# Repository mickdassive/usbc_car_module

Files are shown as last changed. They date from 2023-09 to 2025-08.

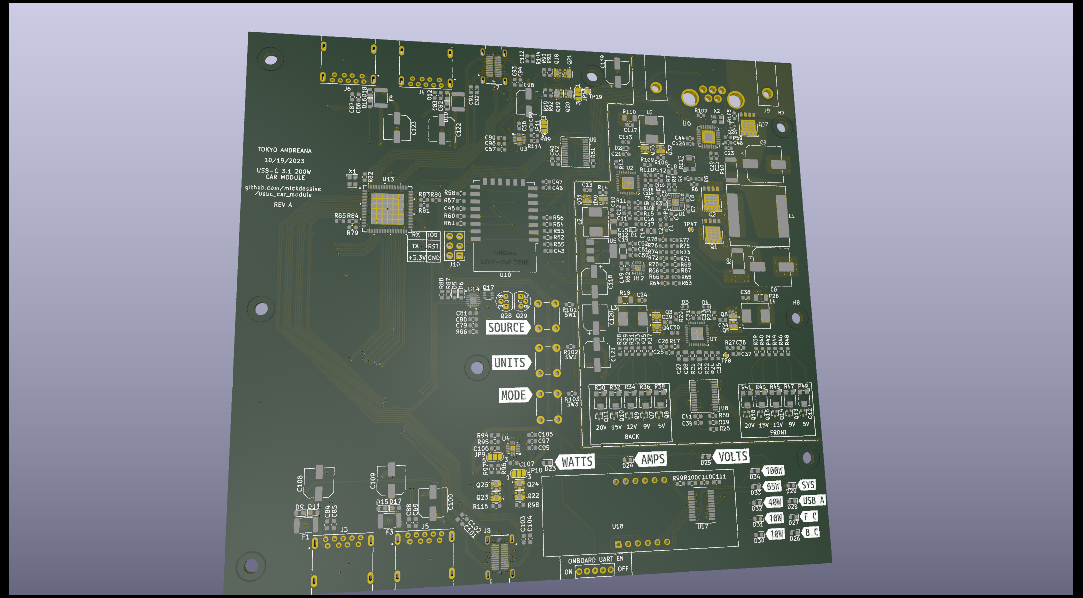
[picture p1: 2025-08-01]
hardware/renders/nopart.png

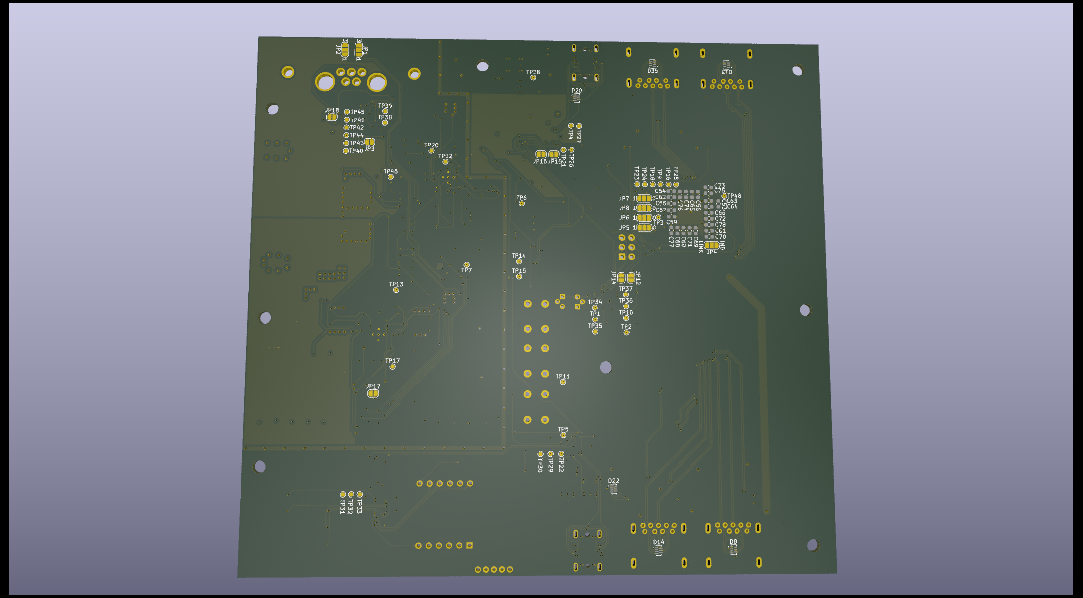
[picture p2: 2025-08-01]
hardware/renders/nopartback.png

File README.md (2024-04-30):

# USB 3.1x1 Hub with USB-C and USB-A Ports

This project is a USB 3.1x1 hub designed with KiCad 8.0 and developed with PlatformIO. It features two USB-C ports (one downstream and one upstream) capable of delivering up to 100W power, along with four regular downstream USB-A ports.

## Features

- USB 3.1x1 hub with USB-C and USB-A ports
- Supports up to 100W power delivery per port
- Onboard UART transceiver for programming the main MCU (ESP-12F)
- Onboard CAN bus transceiver for automotive applications
- Utilizes USB5926C hub chip from Microchip
- USB PD PHYs (PTN110N) from NXP
- Includes a display and ADC for power monitoring:
  - Monitor individual power consumption of USB-C ports (upstream and downstream)
  - Monitor combined total power consumption of USB-A ports
  - Monitor total system power consumption

## Contributors

- [Tokyo Andreana](https://github.com/mickdassive)

## License

This project is licensed under the [GNU General Public License v3.0](LICENSE).

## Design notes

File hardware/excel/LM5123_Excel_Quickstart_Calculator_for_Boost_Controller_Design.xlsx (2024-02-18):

 | LM5123 BOOST Controller Design Tool
ABOUT |  | =Input Box |  |  |  | TERMS OF USE
 |  |  |  |  |  | Rev 0.2 | December-2021
Step 1: Design Specifications
 |  |  | Minimum Input Supply Voltage , VSUPPLY(min) | 10 | V
 |  |  | Typical Input Supply Voltage, VSUPPLY(typ) | 12 | V
 |  |  | Maximum Input Supply Voltage , VSUPPLY(max) | 18 | V
 |  |  | Output Target Voltage, VLOAD | 21 | V
 |  |  | Maximum Output Current , ILOAD | 15.00 | A
 |  |  | Light load operation switching mode | DEM
 |  |  | Free Running Switching Frequency, FSW | 2000 | kHz
 |  |  | Free running Oscillator Set Resistor, RT | 10.10 | kΩ
 |  |  | Output Power, POUT | 315.0 | W
 |  |  | Boost Converter Duty Cycle Limit of LM5123 at VSUPPLY(MIN) | 79.8 | %
 |  |  | Ideal Duty Cycle at VSUPPLY(MIN) | 52.4 | %
Step 2: Filter Inductor
 |  |  | Switching mode at VSUPPLY(min) | CCM
 |  |  | Desired Maximum Inductor Current Ripple Ratio | 10 | %
 |  |  | Recommended Inductance (LM_CALC) | 1.037 | uH
 |  |  | User Selection. Inductance, (LM) | 1 | uH
 |  |  | Max Inductor DCR, RDCR | 1.38 | mΩ
 |  |  | Peak inductor current, ILPK | 32.81 | A
Step 3: Current Sense Resistor Selection
 |  |  | Peak Current Limit Margin | 10 | %
 |  |  | Selected Peak Current limit(ILPK_select) | 37.91 | A
 |  |  | Recommended current sense Resistor (RS) | 1.58 | mΩ
 |  |  | Selected current sense Resistor (RS) | 1.5 | mΩ
 |  |  | Actual inductor peak current limit | 40.00 | A
Step 4: Output Capacitor Selection
 |  |  | Desired load step ripple voltage (ΔvOUT) | 240 | mV
 |  |  | Minimum output capacitance | 492.19 | uF
 |  |  | Selected Output Capacitance (COUT) | 470 | uF
 |  |  | Equivalent COUT ESR (RESR) | 8 | mΩ
Step 6: Soft-Start Capacitor Selection
 |  |  | Suggested minimum soft-start capacitor (CSS_MIN) | 13.16 | nF
 |  |  | Desied soft-start time at minimum input voltage (TSS) | 10 | ms
 |  |  | Calculated soft-start capacitor (CSS) | 381.8181818 | nF
Step 5: UVLO Resistor Divider Selection
 |  |  | Desired voltage On (VUVLO_ON) | 11.2 | V
 |  |  | Desired voltage OFF (VUVLO_OFF) | 10 | V
 |  |  | Calculated top UVLO resistor value (RUVT_CALC) | 94.55 | kΩ
 |  |  | Selected top UVLO resistor value (RUVT) | 100 | kΩ
 |  |  | Bottom UVLO Resistor (RUVB) | 10.891 | kΩ
Step 7: Loop Compensation
 |  |  | Voltage selected (VIN_VAR) | 12V
 |  |  | VREF Resistor Selection
 |  |  | Suggested output voltage range | High
 |  |  | Track pin voltage to set the output voltage (VTRK) | 0.350 | V
 |  |  | Minimum value for (RVREFT_min) | 13.0 | kΩ
 |  |  | Maximum value for (RVREFT_max) | 22.8 | kΩ
 |  |  | Select a top VREF resistor between RVREFT_min and RVREFT_max (RVREFT) | 20 | kΩ
 |  |  | Calculated bottom feedback resistor (RVREFB_calc) | 10.8 | kΩ
 |  |  | Select a bottomresistor based on calculated balue(RVREFB) | 11 | kΩ
 |  |  | Suggested bandwidth (FCO_calc) | 10.1 | kHz
 |  |  | Selected bandwidth (FCO) | 5.5 | kHz
 |  | Calculated |  | Selected
 | RCOMP | 30.3 | kΩ | 35 | kΩ
 | CCOMP | 2.9 | nF | 3.3 | nF
 | CHF | 23.58068651 | pF | 100 | pF
Efficiency / Power Loss Analyzer
Low-Side MOSFET Parameters (QLS)
 |  |  | On-State Resistance, RDS(on) | 8.8 | mΩ
 |  |  | Total Gate Charge, QG | 10 | nC
 |  |  | Gate-Drain Charge, QGD | 2.4 | nC
 |  |  | Gate-Source Charge, QGS | 4.5 | nC
 |  |  | Gate Resistance, RG | 0 | Ω
 |  |  | Gate-Source Threshold Voltage, VTH | 1.7 | V
High-Side MOSFET Parameters (QHS)
 |  |  | On-State Resistance, (RDS(on)) | 8.8 | mΩ
 |  |  | Total Gate Charge, (QG) | 10 | nC
 |  |  | Gate-Drain Charge, (QGD) | 2.4 | nC
 |  |  | Gate-Source Charge, (QGS) | 4.5 | nC
 |  |  | Gate Resistance, (RG) | 0 | Ω
 |  |  | Gate-Source Threshold Voltage, (VTH) | 1.7 | V
 |  |  | Body Diode Reverse Recovery Charge (QRR) | 33 | nC
 |  |  | Body Diode Forward Voltage Drop (VD_BD) | 0.8 | V

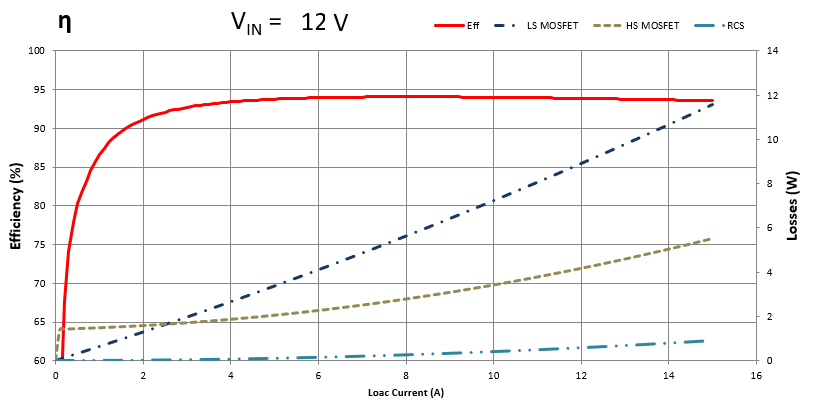
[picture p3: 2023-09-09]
hardware/Capture.PNG

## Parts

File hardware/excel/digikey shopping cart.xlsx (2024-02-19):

Index | Quantity | Part Number | Manufacturer Part Number | Description | Customer Reference | Available | Backorder | Unit Price | Extended Price CAD
1 | 10 | P15436CT-ND | EEH-ZA1E101XP | CAP ALUM HYB 100UF 20% 25V SMD |  | 10 | 0 | 1.356 | 13.56
2 | 1000 | 1276-1935-1-ND | CL10B104KB8NNWC | CAP CER 0.1UF 50V X7R 0603 |  | 1000 | 0 | 0.00665 | 6.65
3 | 100 | 1276-1102-1-ND | CL10A105KA8NNNC | CAP CER 1UF 25V X5R 0603 |  | 100 | 0 | 0.0188 | 1.88
4 | 50 | 445-9050-1-ND | C1608X5R1E475K080AC | CAP CER 4.7UF 25V X5R 0603 |  | 50 | 0 | 0.123 | 6.15
5 | 50 | 490-10731-1-ND | GRM188R61E225KA12D | CAP CER 2.2UF 25V X5R 0603 | 50 | 50 | 0 | 0.08 | 4.00
6 | 50 | 490-GRM188R61E106KA73JCT-ND | GRM188R61E106KA73J | CAP CER 10UF 25V X5R 0603 |  | 50 | 0 | 0.169 | 8.45
7 | 50 | 1292-1494-1-ND | 0603N180J500CT | CAP CER 18PF 50V C0G/NP0 0603 |  | 50 | 0 | 0.019 | 0.95
8 | 25 | 1276-CL10B474KA8VPJCCT-ND | CL10B474KA8VPJC | CAP CER 470NF 25V X7R 0603 |  | 25 | 0 | 0.313 | 7.83
9 | 50 | 399-C0603C471J5GAC7867CT-ND | C0603C471J5GAC7867 | CAP CER 470PF 50V C0G/NP0 0603 |  | 50 | 0 | 0.0414 | 2.07
10 | 10 | 445-14141-1-ND | C1608X5R1E335K080AC | CAP CER 3.3UF 25V X5R 0603 |  | 10 | 0 | 0.279 | 2.79
11 | 10 | P18963CT-ND | EEE-FK1V471SP | CAP ALUM 470UF 20% 35V SMD |  | 10 | 0 | 1.097 | 10.97
12 | 10 | 10-EEE-FN1J121UPCT-ND | EEE-FN1J121UP | CAP ALUM 120UF 20% 63V SMD |  | 10 | 0 | 0.988 | 9.88
13 | 50 | 1292-1424-1-ND | 0603B273K250CT | CAP CER 0.027UF 25V X7R 0603 |  | 50 | 0 | 0.0388 | 1.94
14 | 50 | 399-C0603C151J5GAC7867CT-ND | C0603C151J5GAC7867 | CAP CER 150PF 50V C0G/NP0 0603 |  | 50 | 0 | 0.026 | 1.30
15 | 1000 | 541-10.0KHCT-ND | CRCW060310K0FKEA | RES SMD 10K OHM 1% 1/10W 0603 |  | 1000 | 0 | 0.01246 | 12.46
16 | 1000 | RMCF0603FT100KCT-ND | RMCF0603FT100K | RES 100K OHM 1% 1/10W 0603 |  | 1000 | 0 | 0.00645 | 6.45
17 | 50 | TC33X-103ECT-ND | TC33X-2-103E | TRIMMER 10K OHM 0.1W J LEAD TOP |  | 50 | 0 | 0.3564 | 17.82
18 | 100 | 541-1.00KHCT-ND | CRCW06031K00FKEA | RES SMD 1K OHM 1% 1/10W 0603 |  | 100 | 0 | 0.0213 | 2.13
19 | 100 | 541-0.0GCT-ND | CRCW06030000Z0EA | RES SMD 0 OHM JUMPER 1/10W 0603 |  | 100 | 0 | 0.0175 | 1.75
20 | 10 | WSLP-.01CT-ND | WSLP1206R0100FEA | RES 0.01 OHM 1% 1W 1206 |  | 10 | 0 | 0.685 | 6.85
21 | 50 | 541-4055-1-ND | CRCW0603470RJNEBC | RES SMD 470 OHM 5% 1/10W 0603 |  | 50 | 0 | 0.0204 | 1.02
22 | 50 | 13-RT0603BRE075KLCT-ND | RT0603BRE075KL | RES 5K OHM 0.1% 1/10W 0603 |  | 50 | 0 | 0.1428 | 7.14
23 | 50 | 541-5184-1-ND | CRCW060315R0FKEAC | RES 15 OHM 1% 1/10W 0603 |  | 50 | 0 | 0.0236 | 1.18
24 | 50 | 541-4060-1-ND | CRCW0603330RJNEAC | RES SMD 330 OHM 5% 1/10W 0603 |  | 50 | 0 | 0.0204 | 1.02
25 | 10 | 541-10147-1-ND | WSLP25121L500FEA | RES 0.0015 OHM 1% 3W 2512 |  | 10 | 0 | 1.127 | 11.27
26 | 50 | 541-5.90KHCT-ND | CRCW06035K90FKEA | RES SMD 5.9K OHM 1% 1/10W 0603 |  | 50 | 0 | 0.0252 | 1.26
27 | 50 | 541-5344-1-ND | CRCW060330K0FKEAC | RES 30K OHM 1% 1/10W 0603 |  | 50 | 0 | 0.0236 | 1.18
28 | 50 | 13-RC0603FR-1322KLCT-ND | RC0603FR-1322KL | RES 22K OHM 1% 1/10W 0603 |  | 50 | 0 | 0.017 | 0.85
29 | 50 | 13-RC0402FR-0735KLCT-ND | RC0402FR-0735KL | RES 35K OHM 1% 1/16W 0402 |  | 50 | 0 | 0.0134 | 0.67
30 | 50 | 13-RC0603FR-1020KLCT-ND | RC0603FR-1020KL | RES 20K OHM 1% 1/10W 0603 |  | 50 | 0 | 0.017 | 0.85
31 | 25 | 541-120HCT-ND | CRCW0603120RFKEA | RES SMD 120 OHM 1% 1/10W 0603 |  | 25 | 0 | 0.039 | 0.98
32 | 50 | 541-4057-1-ND | CRCW060310R0JNEAC | RES SMD 10 OHM 5% 1/10W 0603 |  | 50 | 0 | 0.0204 | 1.02
33 | 10 | 541-4046-1-ND | CRCW060312K0FKEAC | RES SMD 12K OHM 1% 1/10W 0603 |  | 10 | 0 | 0.038 | 0.38
34 | 5 | TC33X-102ECT-ND | TC33X-2-102E | TRIMMER 1K OHM 0.1W J LEAD TOP |  | 5 | 0 | 0.43 | 2.15
35 | 4 | 541-1008-1-ND | IHLP2525CZER2R2M01 | FIXED IND 2.2UH 8A 20 MOHM SMD |  | 4 | 0 | 1.72 | 6.88
36 | 2 | 541-1250-1-ND | IHLP6767GZER1R0M01 | FIXED IND 1UH 48A 1.38 MOHM SMD |  | 2 | 0 | 5.86 | 11.72
37 | 2 | 541-1004-1-ND | IHLP2525CZERR68M01 | FIXED IND 680NH 15.5A 5.5MOHM SM |  | 2 | 0 | 1.84 | 3.68
38 | 2 | 541-IHLP2525CZER1R0M11CT-ND | IHLP2525CZER1R0M11 | FIXED IND 1UH 12.5A 8 MOHM SMD |  | 2 | 0 | 1.84 | 3.68
39 | 10 | RB520S30T1GOSCT-ND | RB520S30T1G | DIODE SCHOTTKY 30V 200MA SOD523 |  | 10 | 0 | 0.157 | 1.57
40 | 25 | 1801-TS4148RCGCT-ND | TS4148 RCG | DIODE GEN PURP 75V 100MA 0603 |  | 25 | 0 | 0.195 | 4.88
41 | 10 | UCLAMP0501HCT-ND | UCLAMP0501H.TCT | TVS DIODE 5VWM 12.5VC SOD523 |  | 10 | 0 | 0.701 | 7.01
42 | 100 | 67-1548-1-ND | SML-LX0603IW-TR | LED RED DIFFUSED SMD |  | 100 | 0 | 0.1758 | 17.58
43 | 4 | 296-LM5143QRWGRQ1CT-ND | LM5143QRWGRQ1 | IC POWER MANAGEMENT |  | 4 | 0 | 19.33 | 77.32
44 | 10 | NCP177AMX120TCGOSCT-ND | NCP177AMX120TCG | IC REG LINEAR 1.2V 500MA 4XDFN |  | 10 | 0 | 0.533 | 5.33
45 | 4 | PI4IOE5V6416LEXDICT-ND | PI4IOE5V6416LEX | IC XPNDR 400KHZ I2C 24TSSOP |  | 4 | 0 | 2.26 | 9.04
46 | 4 | 568-13082-1-ND | PTN5100BSMP | IC USB PD PHY TYPE C 20HVQFN |  | 4 | 0 | 4.22 | 16.88
47 | 2 | 296-LM51231QRGRRQ1CT-ND | LM51231QRGRRQ1 | 2.2-MHZ WIDE-VIN, SYNCHRONOUS BO |  | 2 | 0 | 6.47 | 12.94
48 | 2 | MCP2558FDT-H/MNYCT-ND | MCP2558FDT-H/MNY | IC TRANSCEIVER 1/1 8TDFN |  | 2 | 0 | 1.65 | 3.30
49 | 2 | 296-ADS7128IRTERCT-ND | ADS7128IRTER | IC ADC 12BIT SAR 16WQFN |  | 2 | 0 | 10.04 | 20.08
50 | 2 | 150-USB5926CT/KDCT-ND | USB5926CT/KD | IC HUB CNTRL USB |  | 2 | 0 | 16.12 | 32.24
51 | 2 | 336-5886-1-ND | CP2102N-A02-GQFN20R | IC USB TO UART BRIDGE QFN20 |  | 2 | 0 | 6.74 | 13.48
52 | 2 | AS1115-BSSTCT-ND | AS1115-BSST | IC DRVR 64 LED 7SEG 8 DGT 24QSOP |  | 2 | 0 | 9.99 | 19.98
53 | 2 | XC1433CT-ND | ECS-2033-250-BN | XTAL OSC XO 25.0000MHZ CMOS SMD |  | 2 | 0 | 1.32 | 2.64
54 | 10 | EG1828-ND | TL1105F250Q | SWITCH TACTILE SPST-NO 0.05A 12V |  | 10 | 0 | 0.302 | 3.02
55 | 100 | NTA7002NT1GOSCT-ND | NTA7002NT1G | MOSFET N-CH 30V 154MA SC75 |  | 100 | 0 | 0.1621 | 16.21
56 | 25 | 1727-1244-1-ND | PMPB11EN,115 | MOSFET N-CH 30V 9A DFN2020MD-6 |  | 25 | 0 | 0.533 | 13.33
57 | 25 | 1727-PMPB09R5VPXCT-ND | PMPB09R5VPX | PMPB09R5VP - 12 V, P-CHANNEL TRE |  | 25 | 0 | 0.526 | 13.15
58 | 4 | FDMS8820CT-ND | FDMS8820 | MOSFET N-CH 30V 28A/116A 8PQFN |  | 4 | 0 | 1.78 | 7.12
59 | 2 | 785-1309-1-ND | AON7421 | MOSFET P-CH 20V 30A/50A 8DFN |  | 2 | 0 | 1.54 | 3.08
60 | 10 | WM10413CT-ND | 0483930003 | CONN RCPT USB3.0 TYPEA 9POS R/A |  | 10 | 0 | 3.956 | 39.56
61 | 4 | 2073-USB4200-03-ACT-ND | USB4200-03-A | USB 3.2 GEN 2 TYPE C REC, SMT,FL |  | 4 | 0 | 4.19 | 16.76
62 | 25 | 1727-2028-1-ND | PUSB3AB6Z | TVS DIODE 3.3VWM 6VC 7XSON |  | 25 | 0 | 0.4772 | 11.93

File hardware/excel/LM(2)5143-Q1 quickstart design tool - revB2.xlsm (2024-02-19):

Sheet: Design Regulator
LM(2)5143/-Q1 Synchronous Buck Controller Design Tool
 |  |  |  |  |  |  |  |  |  |  |  | http://www.ti.com/product/lm5175
About |  | xx (http://www.ti.com/pol) |  |  | = Input Box |  |  |  |  |  |  | TERMS OF USE
Step 1: Operating Specifications
 |  |  | Input Voltage – Min, VIN(min) | 20 | V
 |  |  | Input Voltage – Nom, VIN(nom) | 21 | V
 |  |  | Input Voltage – Max, VIN(max) | 26 | V
 |  |  | Output Voltage, VOUT | 3.3 | V |  |  | Output Voltage, VOUT2 | 5 | V
 |  |  | Full Load Output Current, IOUT | 4 | A |  |  | Full Load Output Current, IOUT2 | 8 | A
 |  |  | Switching Frequency, FSW | 2100 | kHz
 |  |  | Frequency Set Resistor, RT | 10.5 | kΩ
 |  |  | Ambient Temperature, TA | 25 | °C
Step 2: Current Sense Resistors
 |  |  | Required IOCP Setpoint at VIN(nom) | 9 | A |  |  | Required IOCP Setpoint at VIN(nom) | 5 | A
 |  |  | Recommended Sense Resistance | 7.3 | mΩ |  |  | Recommended Sense Resistance | 12.3 | mΩ
 |  |  | Sense Resistance, RS | 10 | mΩ |  |  | Sense Resistance, RS2 | 10 | mΩ
 |  |  | Min Inductor Sat Current, ILO(SAT) | 7.3 | A |  |  | Min Inductor Sat Current, ILO2(SAT) | 7.3 | A
 |  |  | Max power loss in shunt | 0.40 | W |  |  | Max power loss in shunt RS2 | 0.41 | W
 |  |  | VIN(min) | 6.3 | A |  |  | VIN(min) | 6.4 | A
 |  | IOUT(typ) at OCP Inception: | VIN(nom) | 6.3 | A |  | IOUT2(typ) at OCP Inception: | VIN(nom) | 6.4 | A
 |  |  | VIN(max) | 6.3 | A |  |  | VIN(max) | 6.3 | A
Step 3: Buck Inductances
 |  |  | Ch1 Recommended Inductance | 0.65 | µH |  |  | Ch2 Recommended Inductance | 0.99 | µH
 |  |  | Ch1 Inductance, LO1 | 0.68 | µH |  |  | Ch2 Inductance, LO2 | 1 | µH
 |  |  | Ch1 Inductor DCR | 5 | mΩ |  |  | Ch2 Inductor DCR | 9 | mΩ
 |  |  | DIL as a % at VIN(nom) | 49.4855737 | % |  |  | DIL2 as a % at VIN(nom) | 23.27640734 | %
Step 4: Output Capacitors
 |  |  | Ch1 Output Voltage Ripple Spec | 50 | mVpk-pk |  |  | Ch2 Output Voltage Ripple Spec | 50 | mVpk-pk
 |  |  | Ch1 Minimum Output Capacitance | 2.4 | µF |  |  | Ch2 Minimum Output Capacitance | 2.2 | µF
 |  |  | Output Capacitance (derated), COUT | 4.7 | µF |  |  | Ch2 Output Cap (derated), COUT2 | 4.7 | µF
 |  |  | Ch1 Maximum Permitted ESR | 21.8556349 | mΩ |  |  | Ch2 Maximum Permitted ESR | 23.67688858 | mΩ
 |  |  | Ch1 Output Capacitor ESR | 2 | mΩ |  |  | Ch2 Output Capacitor ESR | 2 | mΩ |  |  |  | ** Tie VCCX to GND if not used **
 |  |  | Resulting Output Voltage Ripple (max) | 25.37934518 | mVpk-pk |  |  | Resulting Output Voltage Ripple (max) | 23.87524009 | mVpk-pk
 |  |  | Output Capacitor RMS Current (max) | 0.59 | A (rms) |  |  | Output Capacitor RMS Current (max) | 0.57 | A (rms)
Step 5: Input Capacitors
 |  |  | Input Voltage Ripple Spec | 250 | mVpk-pk
 |  |  | Minimum Input Capacitance | 10 | µF
 |  |  | Input Capacitance, CIN | 50 | µF
 |  |  | Maximum Permitted ESR | 47.9 | mΩ
 |  |  | Input Capacitor ESR | 1 | mΩ
 |  |  | Resulting Input Voltage Ripple (max) | 14.54938104 | mVpk-pk
 |  |  | Input Capacitor RMS Current (max) | 3.50 | A (rms)
Step 6: Soft-start, Hiccup, Dither, DEMB, MODE
 |  |  | Soft-Start Time, tSS | 3 | ms
 |  |  | Soft-Start Capacitance, CSS | 100 | nF
 |  |  | Hiccup Fault Time, tRES | 30 | ms
 |  |  | RES Capacitance, CRES | 470 | nF
 |  |  | Modulating Frequency | 9
 |  |  | *Tie DITH to VDDA
 |  |  | *Tie DEMB to AGND
 |  |  | * Tie MODE to AGND
Step 7: Compensation Design
 |  |  | Ch1 Load Pole Frequency | 53012.81569 | Hz |  |  | Ch2 Load Pole Frequency | 62178.71097 | Hz
 |  |  | Ch1 ESR Zero Frequency | 16931.37694 | kHz |  |  | Ch2 ESR Zero Frequency | 16931.37694 | kHz
 |  |  | Ch1 Desired Crossover Frequency | 60 | kHz |  |  | Ch2 Desired Crossover Frequency | 60 | kHz
 |  |  | Ch1 Error Amp Pole Frequency | 0.1 | Hz |  |  | Ch2 Error Amp Pole Frequency | 0.1 | Hz
 |  |  | * Tie FB1 to VDDA for Ch1 3.3V Out | 10 | kΩ |  |  | * Tie FB2 to AGND for Ch2 5V Out | 10 | kΩ
 |  |  |  | 2.21 | kΩ |  |  |  | 1.37 | kΩ
Compensation Components
 | Calculated / | Std Values | Std Values |  | Actual P/Z Frequencies
RC1 | 1.0 | 0.976 | 0.976 | kΩ | 0.09210215058 | Hz (FPEA)
CC1 | 27.2 | 27 | 27 | nF | 6.0 | kHz (FZCOMP)
CC2 | 149.1727539 | 150 | 150 | pF | 1042.863431 | kHz (FPCOMP)
RC2 | 1.5 | 1.47 | 1.47 | kΩ | 0.1381521595 | Hz (FPEA2)
CC3 | 18.0 | 18 | 18 | nF | 6.0 | kHz (FZCOMP2)
CC4 | 96.28951035 | 100 | 100 | pF | 1017.88605 | kHz (FPCOMP2) |  |  |  |  | ** Specify Inductor Core Loss ** | 0.3 | W
Efficiency / Power Loss Analyzer
Step 8: Efficiency
 |  |  |  |  | Ch1 Power MOSFETs | (Q1, Q2) |  | Ch2 Power MOSFETs | (Q3, Q4)
 |  |  |  | NVMFS5H663, NVMFS5C628NL |  |  | NVMFS5H663, NVMFS5C628NL
 |  |  |  | High-side | Low-side |  | High-side | Low-side
 |  |  | On-State Resistance, RDS(on) | 6.0 | 2.5 | mΩ | 6 | 2.5 | mΩ
 |  |  | Total Gate Charge, QG | 8 | 25 | nC | 8 | 25 | nC
 |  |  | Gate-Drain Charge, QGD | 1.4 | 4.5 | nC | 1.4 | 4.5 | nC
 |  |  | Gate-Source Charge, QGS | 3.8 | 12 | nC | 3.8 | 12 | nC
 |  |  | Output Charge, QOSS |  | 30 | nC |  | 30 | nC
 |  |  | Output Capacitance, COSS | 213 | 1700 | pF | 213 | 1700 | pF
 |  |  | Gate Resistance, RG | 0.5 | 0.5 | Ω | 0.5 | 0.5 | Ω
 |  |  | Transconductance, gFS | 64 | 280 | S | 64 | 280 | S
 |  |  | Gate-Source Threshold Voltage, VTH | 2.9 | 3 | V | 2.9 | 3 | V
 |  |  | Body Diode Forward Voltage, VBD | 0.7 | 0.7 | V | 0.7 | 0.7 | V
 |  |  | Body Diode Rev Recovery Charge, QRR |  | 60 | nC |  | 60 | nC
 |  |  | Thermal Resistance, θJA | 50 | 38 | °C/W | 50 | 38 | °C/W
External Schottky Diode (if applicable) |  |  |  | Ch1 | Ch2
 |  |  | Schottky Fwd Voltage, VFWDsch | 0 | 0 | V
 |  |  | Schottky Rev Recovery Charge, QRRsch | 0 | 0 | nC
Step 9: IC Power Loss
 |  |  | IC Power Dissipation | 0.69 | W
 |  |  | IC Junction Temperature (estimate) | 49.1 | °C

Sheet: BOM & Schematic
** Tie DEMB to VDDA for FPWM, AGND for DCM ** |  |  |  |  |  | ** Tie VCCX to GND if not used **
** Tie MODE to VDDA for Single, AGND for Dual Outputs **
** For Dual-Output Operation, tie FB1/FB2 to to VDDA for Fixed 3.3V, AGND for Fixed 5V Output **
** For Single-Output Operation in 2-Phase Mode, tie MODE to VDDA and use FB1 to set VOUT. Connect FB2 to AGND to disable EA of channel 2 **
** For Single-Output Operation in 3-Phase or 4-Phase Mode, tie all MODE pins to VDDA. Use FB1 of master IC to set VOUT. Connect FB2 of master IC to AGND. Connect FB2 of slave IC to VDDA to configure it as a slave **
VIN = 20 V to 26 V, VOUT1 = 3.3 V, IOUT1 = 4A, VOUT2 = 5 V, IOUT2 = 8 A, Fsw = 2100 kHz, Current Limit = 9 A
High Efficiency Synchronous Buck Regulator BOM
Count | Ref Des | Value | Description |  | Size | Part Number | MFR
2 | CBOOT1, CBOOT2 | 0.1µF | Capacitor, Ceramic,0.1-µF, 25V, X7R, 20% |  | 0603 | Std | Std
1 | CC1 | 27nF | Capacitor, Ceramic,27-nF, 16V, X7R, 10% |  | 0603 | Std | Std
1 | CC2 | 150pF | Capacitor, Ceramic,150-pF, 50V, NP0, 5% |  | 0603 | Std | Std
1 | CC3 | 18nF | Capacitor, Ceramic,18-nF, 16V, X7R, 10% |  | 0603 | Std | Std
1 | CC4 | 100pF | Capacitor, Ceramic,100-pF, 50V, NP0, 5% |  | 0603 | Std | Std
1 | CRES | 470nF | Capacitor, Ceramic,470-nF, 16V, X7R, 10% |  | 0603 | Std | Std
1 | CDITH | 10nF | Capacitor, Ceramic,10-nF, 16V, X7R, 10% |  | 0603 | Std | Std
5 | CIN | 10µF | Capacitor, Ceramic,10-µF, 50V, X7R, 20% |  | 1210 | Std | Std
1 | COUT | 47µF | Capacitor, Ceramic,47-µF, 10V, X7R, 20% |  | 1210 | Std | Std
2 | CSS1, CSS2 | 100nF | Capacitor, Ceramic,100-nF, 16V, X7R, 10% |  | 0603 | Std | Std
3 | CVCC1, CVCC2, CVCCX | 2.2µF | Capacitor, Ceramic,2.2-µF, 25V, X7R, 20% |  | 0603 | Std | Std
1 | CVDDA | 0.47µF | Capacitor, Ceramic,0.47-µF, 25V, X7R, 20% |  | 0603 | Std | Std
2 | DBOOT1, DBOOT2 | See description | Schottky Diode, 60V, 200mA |  | - | - | Various
1 | LO1 | 0.68µH | Inductor, 0.68µH, 5mΩ, >12A |  | - | - | Various
1 | LO2 | 1µH | Inductor, 1µH, 9mΩ, >7A |  | - | - | Various
2 | Q1, Q2 | See description | MOSFET, N-CH, 40V,6mΩ |  | Std | NVMFS5H663, NVMFS5C628NL | -
2 | Q3, Q4 | See description | MOSFET, N-CH, 40V,6mΩ |  | Std | NVMFS5H663, NVMFS5C628NL | -
1 | RC1 | 0.976k | Resistor, Chip,0.976-kΩ, 1/16W, 1% |  | 0603 | Std | Std
1 | RC2 | 1.47k | Resistor, Chip,1.47-kΩ, 1/16W, 1% |  | 0603 | Std | Std
1 | RS1 | 10m | Resistor, Chip,10-mΩ, 2W, 1% |  | 0508 | Std | Std
1 | RS2 | 10m | Resistor, Chip,10-mΩ, 2W, 1% |  | 0508 | Std | Std
1 | RT | 10.5k | Resistor, Chip,10.5-kΩ, 1/16W, 1% |  | 0603 | Std | Std
1 | RFB1 | 10k | Resistor, Chip,10-kΩ, 1/16W, 1% |  | 0603 | Std | Std
1 | RFB2 | 2.21k | Resistor, Chip,2.21-kΩ, 1/16W, 1% |  | 0603 | Std | Std
1 | RFB3 | 10k | Resistor, Chip,10-kΩ, 1/16W, 1% |  | 0603 | Std | Std
1 | RFB4 | 1.37k | Resistor, Chip,1.37-kΩ, 1/16W, 1% |  | 0603 | Std | Std
2 | RPGOOD1, RPGOOD2 | 100k | Resistor, Chip,100-kΩ, 1/16W, 1% |  | 0603 | Std | Std
2 | RPG1, RPG2 | 100k | Resistor, Chip,100-kΩ, 1/16W, 1% |  | 0603 | Std | Std
1 | RDEMB | 100k | Resistor, Chip,100-kΩ, 1/16W, 1% |  | 0603 | Std | Std
1 | RVIN | 2.2 | Resistor, Chip,2.2-Ω, 1/16W, 1% |  | 0603 | Std | Std
1 | U1 | LM5143-Q1 | IC, LM5143-Q1, Buck PWM Controller, 3.5V–65V Input |  | VQFN-40 | LM5143QRWGRQ1 | TI
NOTES:
** For information on TI NexFETTM MOSFETs, see ** |  |  | http://www.ti.com/nexfet | **
** Inductor saturation current should be higher than the peak inductor current at the OCP setpoint for all input voltages and operating temperatures **
** Effective input and output capacitances should be appropriately derated for applied voltage and temperature, particularly with ceramics **

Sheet: EVM
LM(2)5143/-Q1 Quickstart Design Tool
 | LM5143-Q1EVM-2100 PCB Layout

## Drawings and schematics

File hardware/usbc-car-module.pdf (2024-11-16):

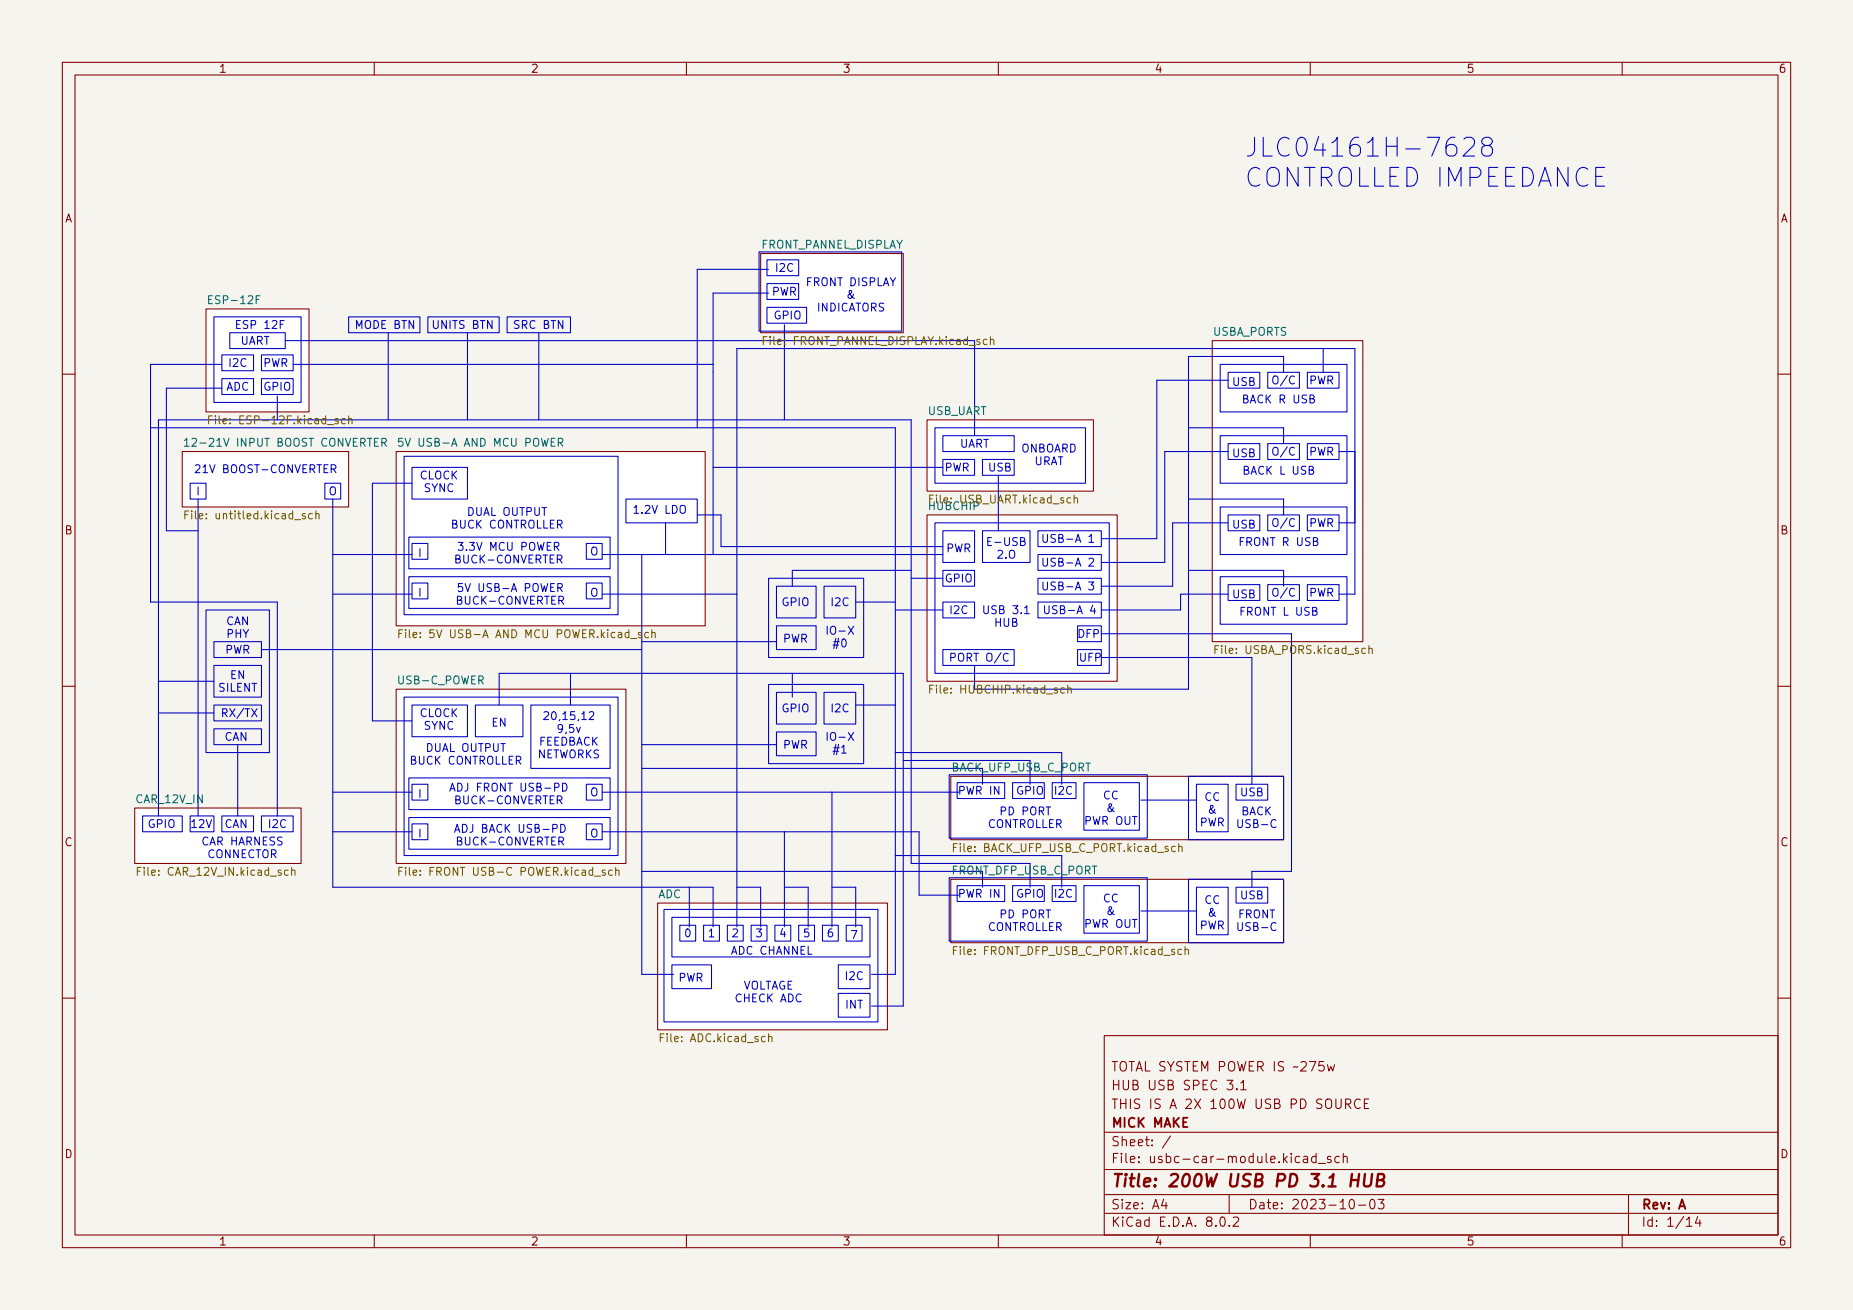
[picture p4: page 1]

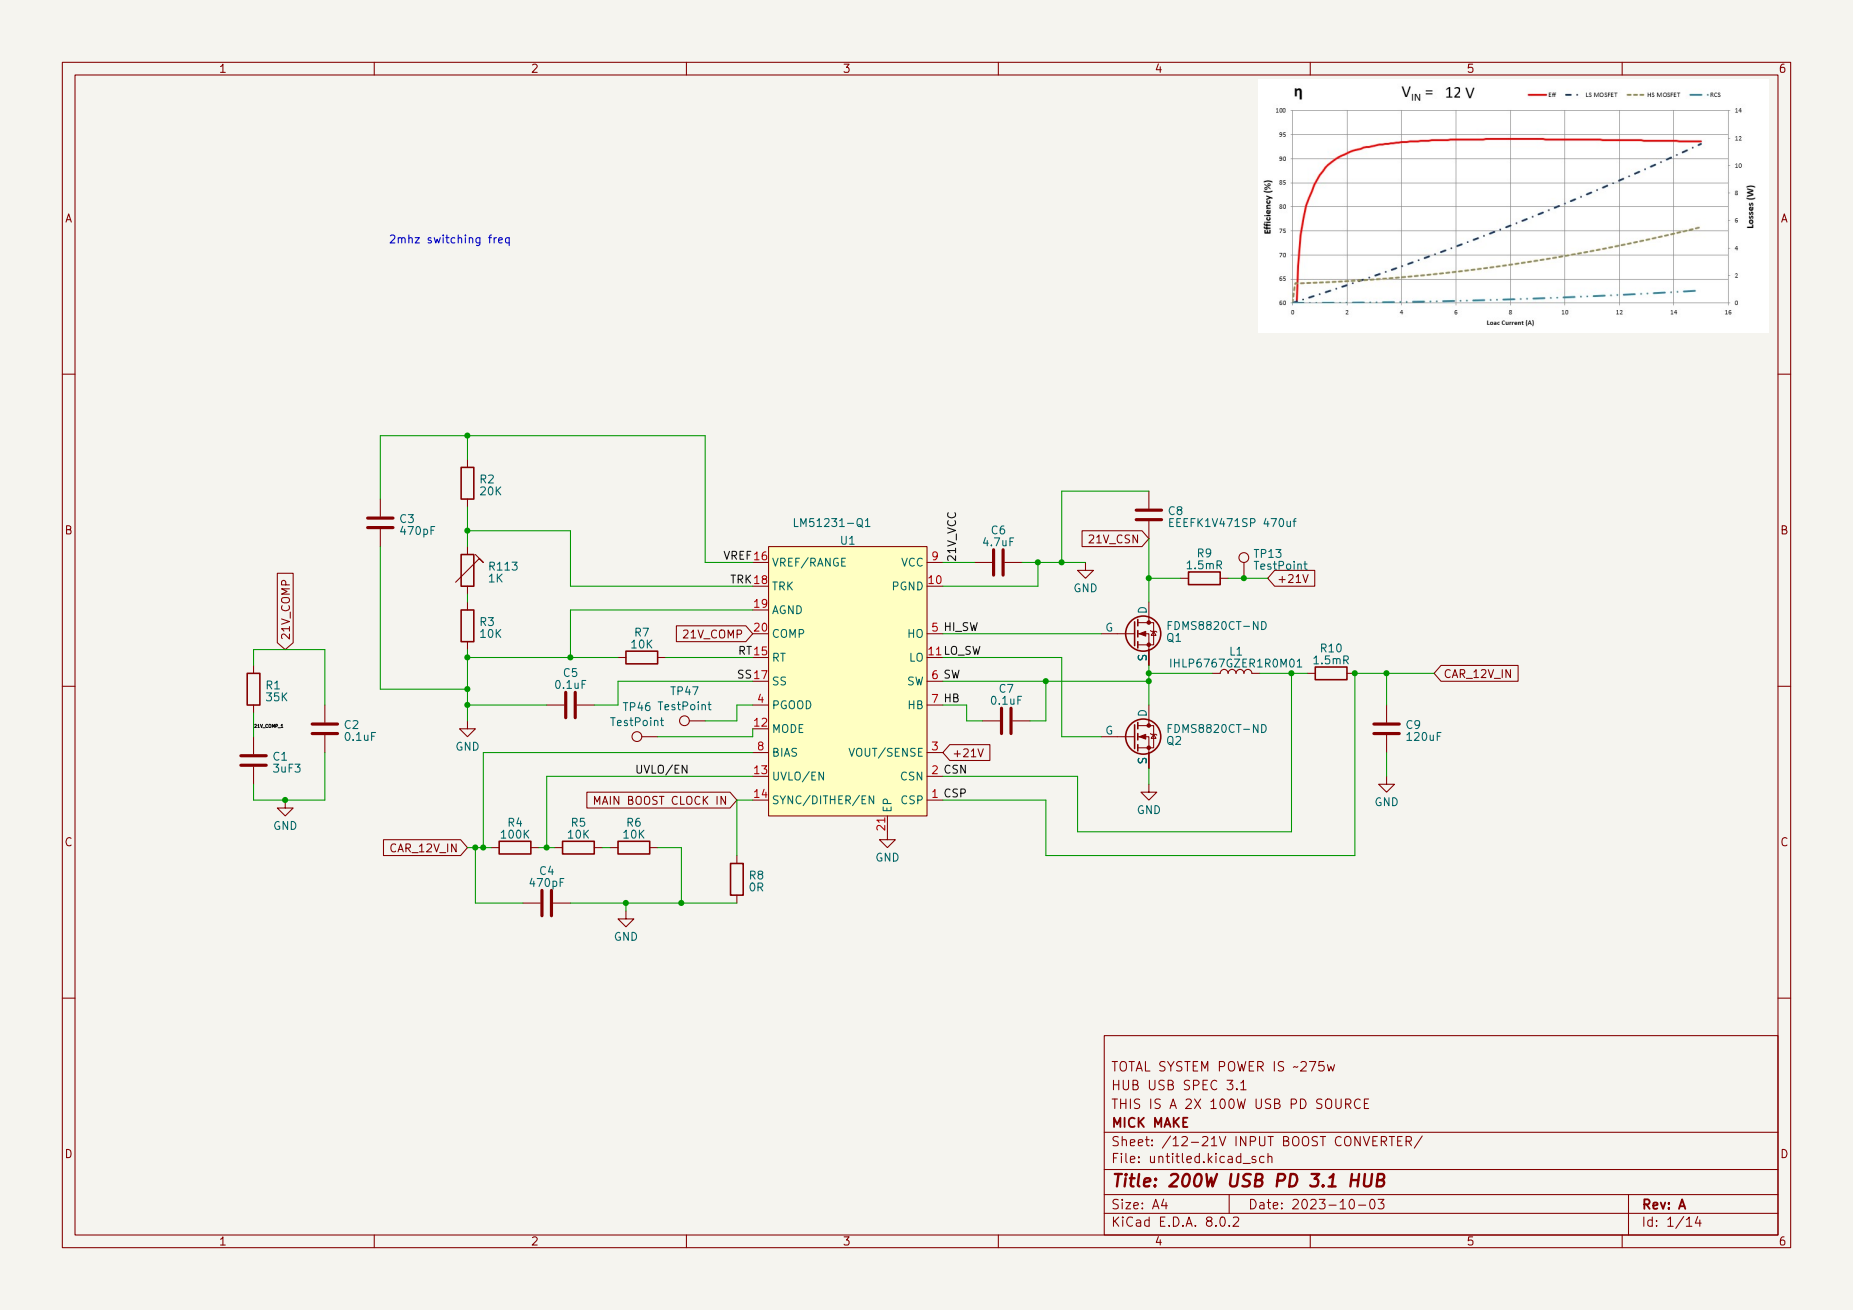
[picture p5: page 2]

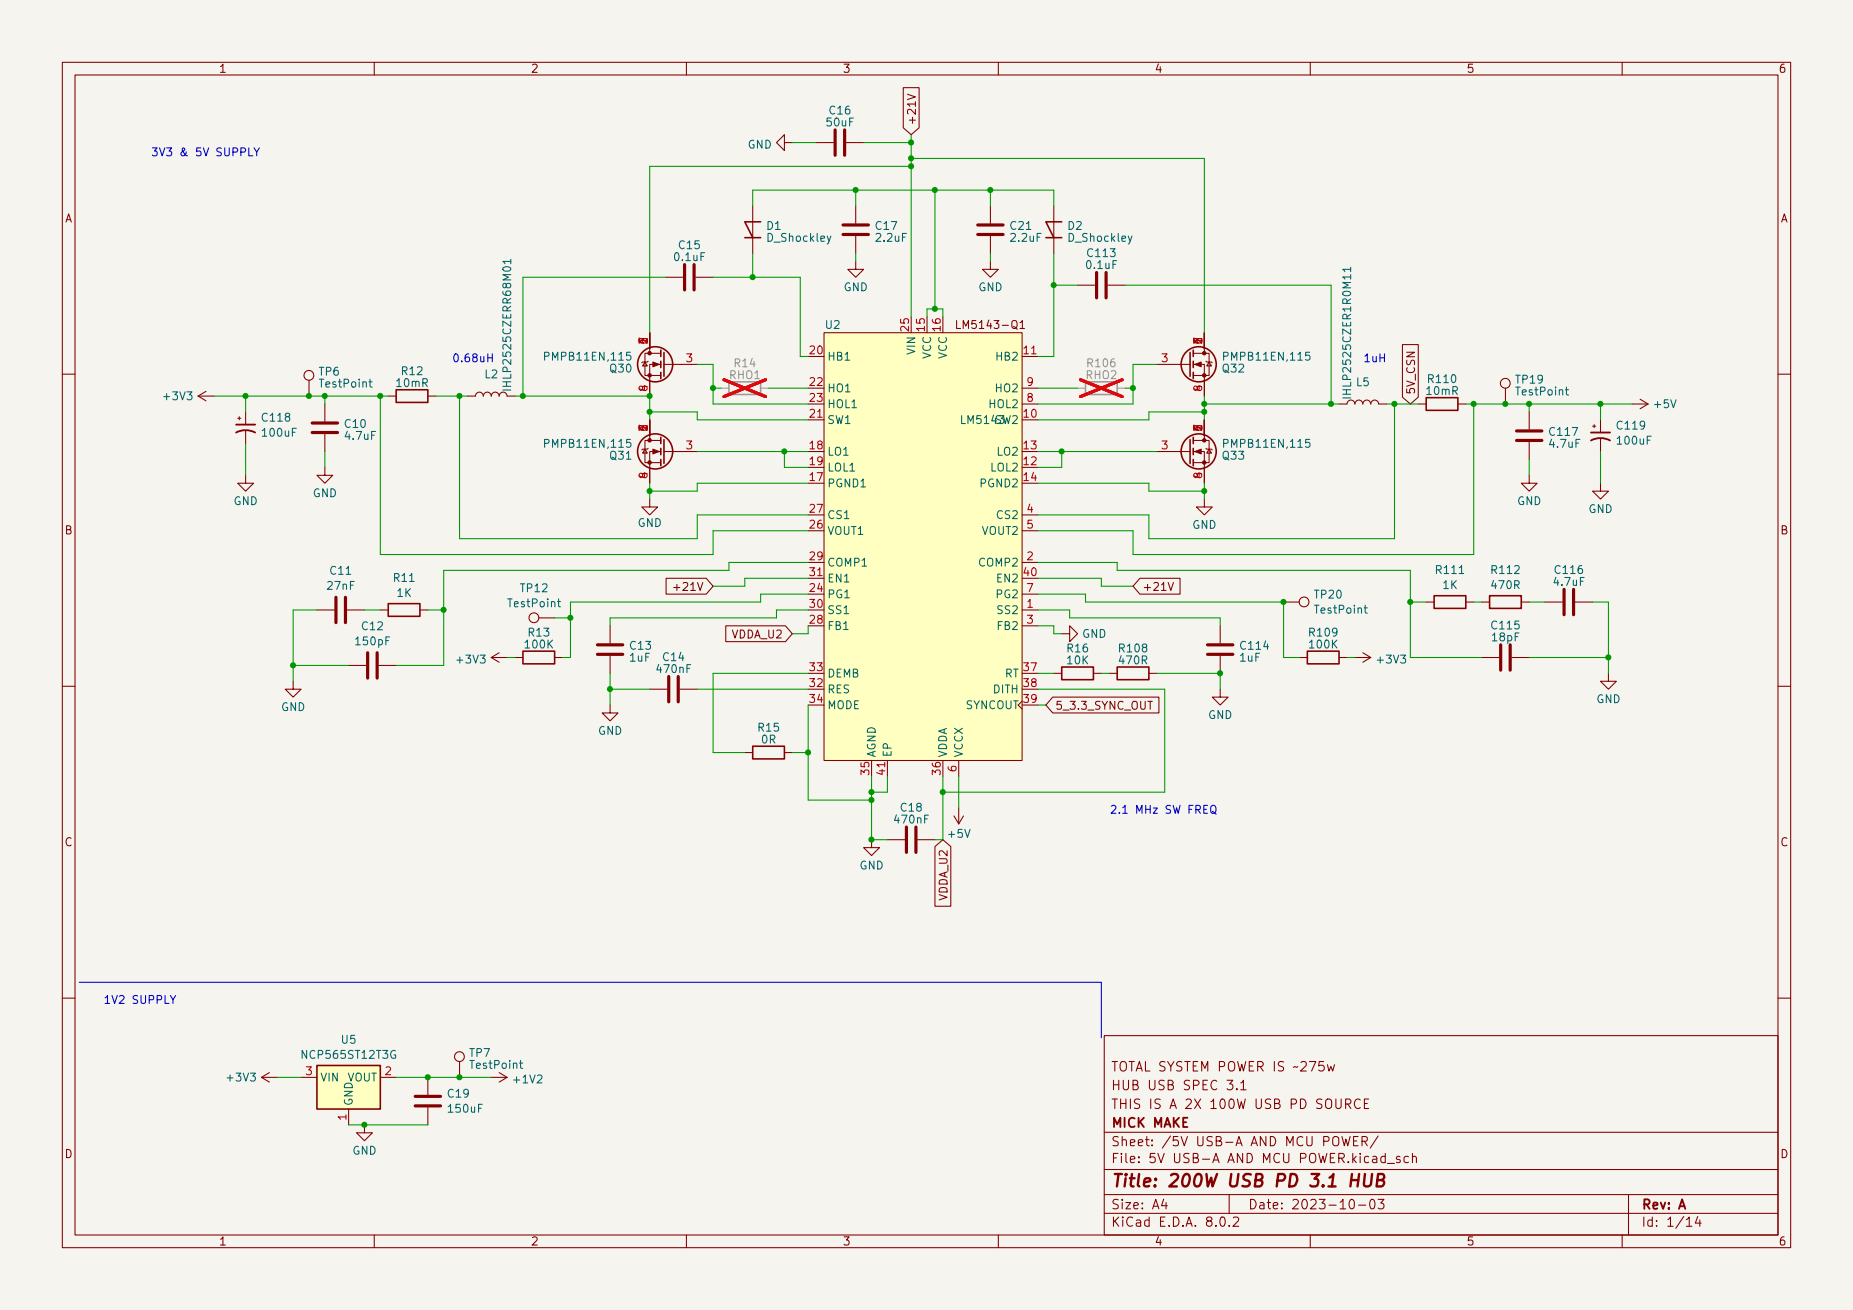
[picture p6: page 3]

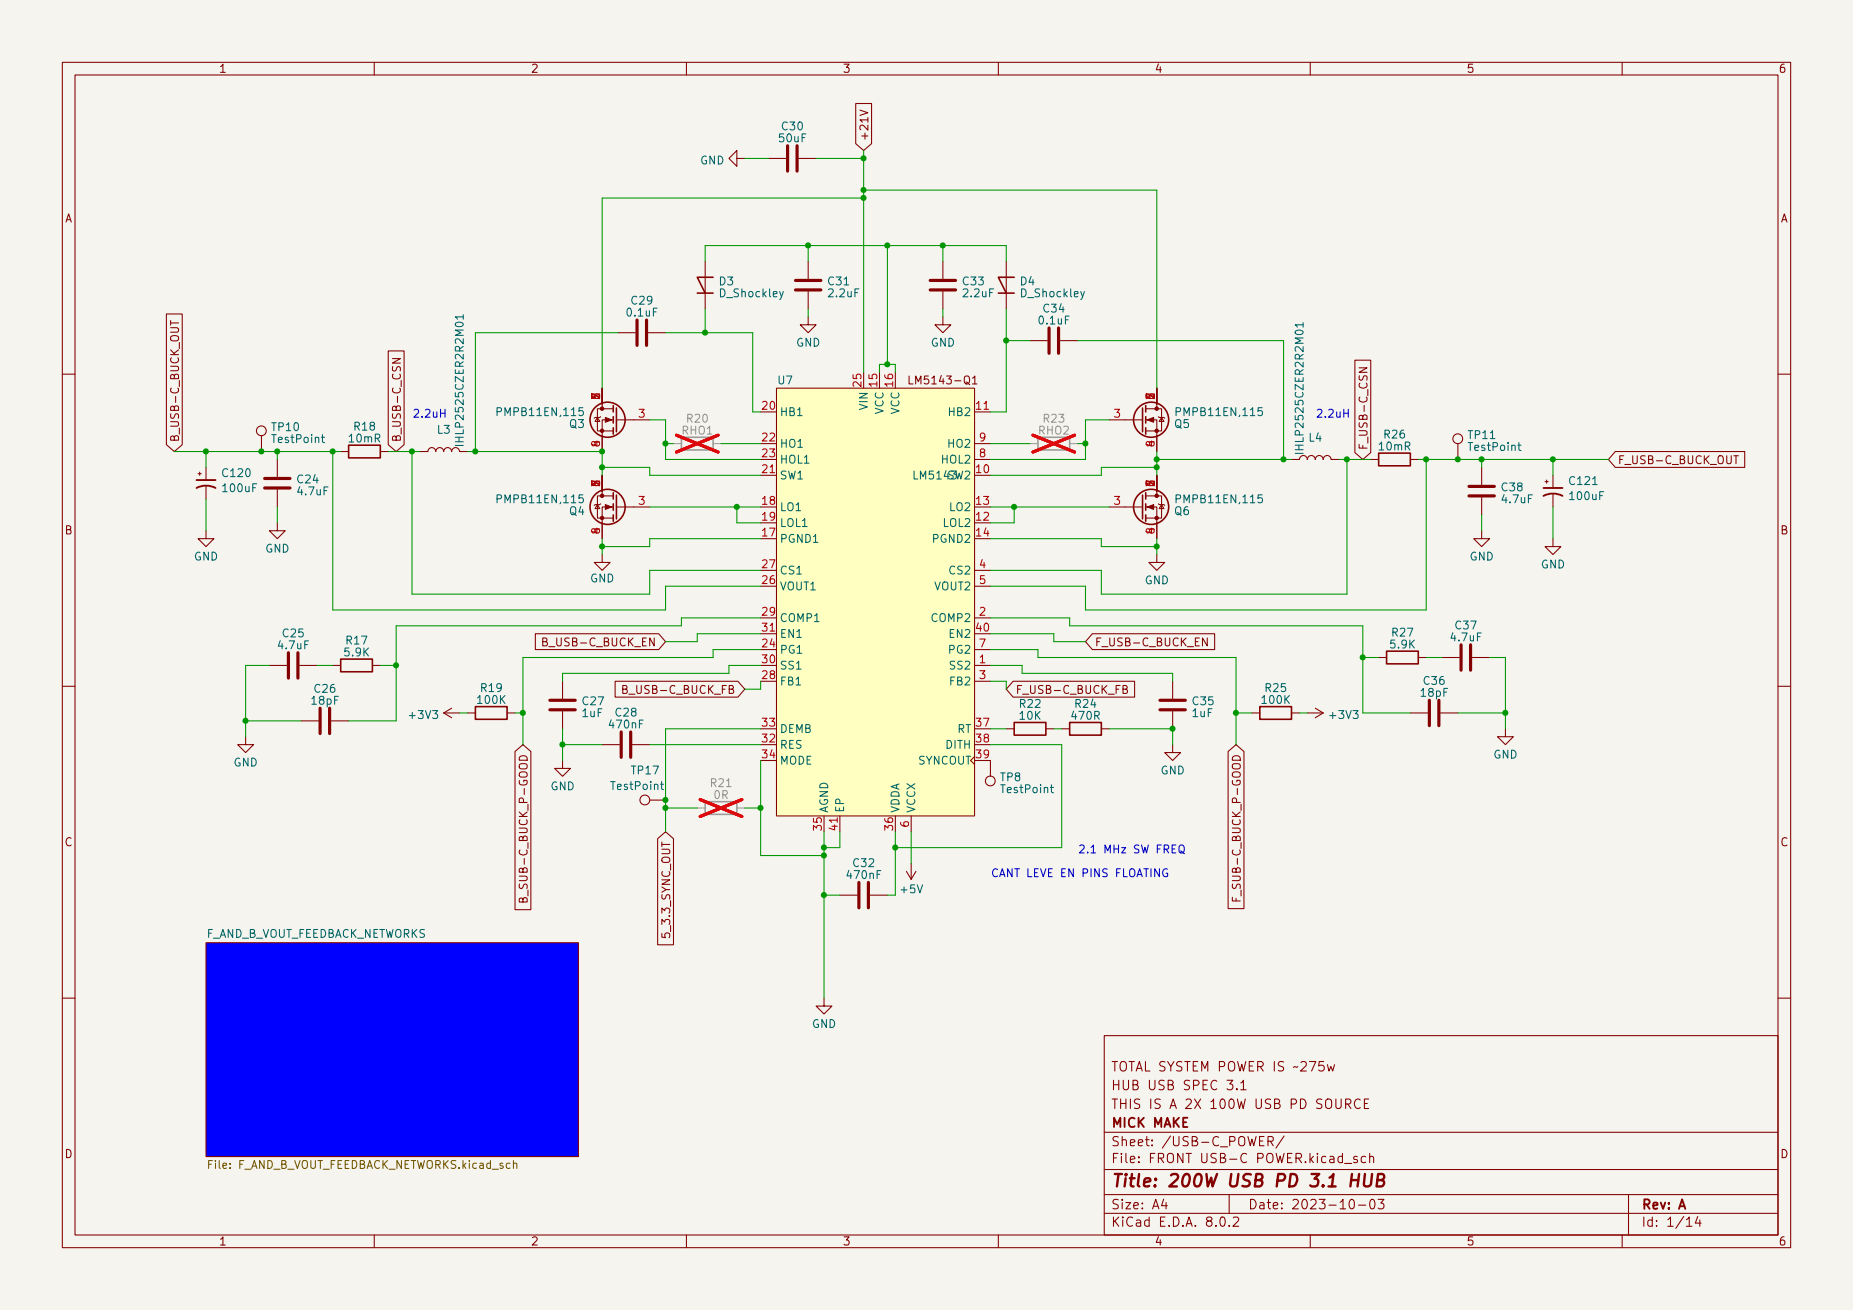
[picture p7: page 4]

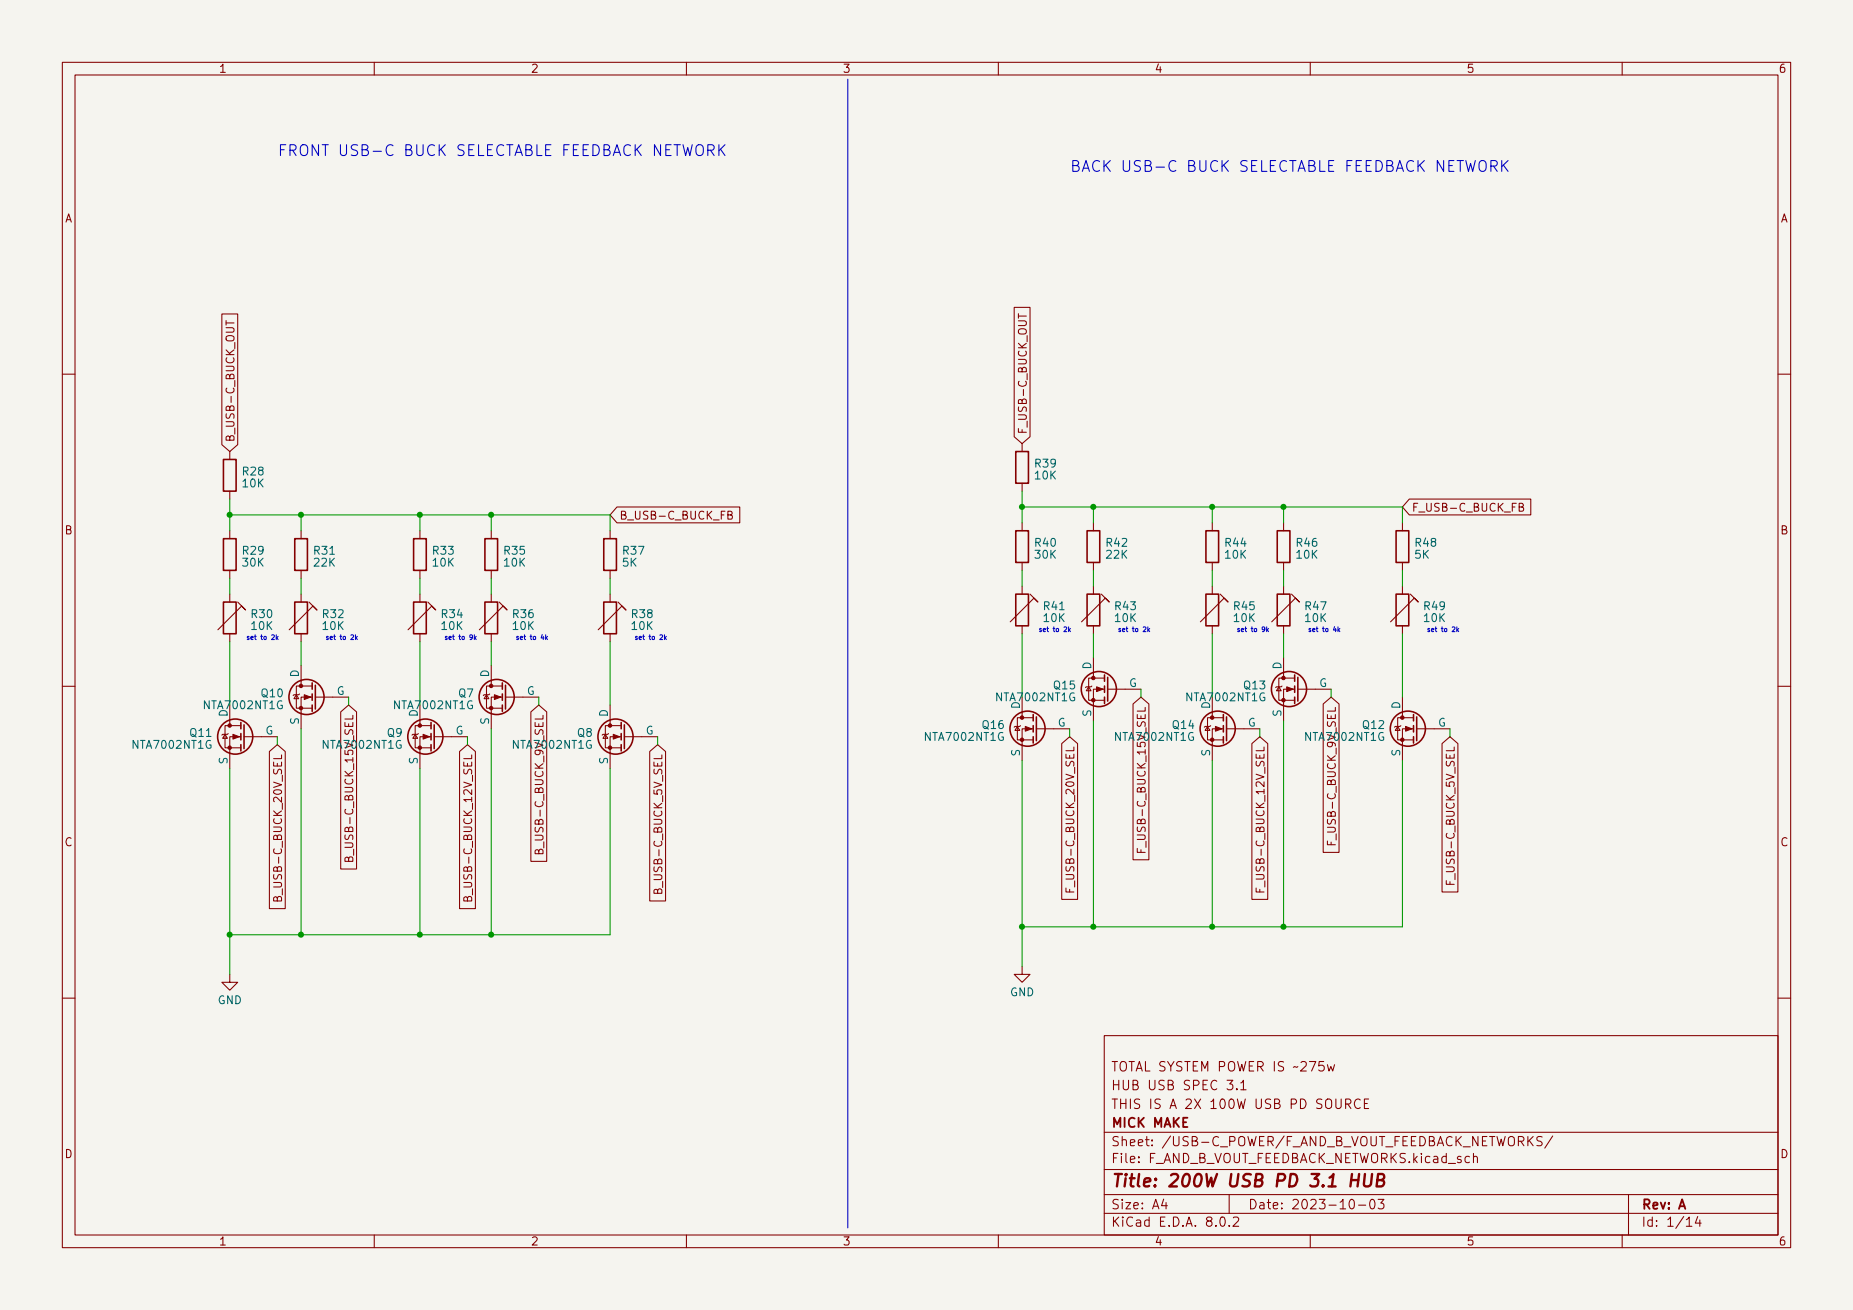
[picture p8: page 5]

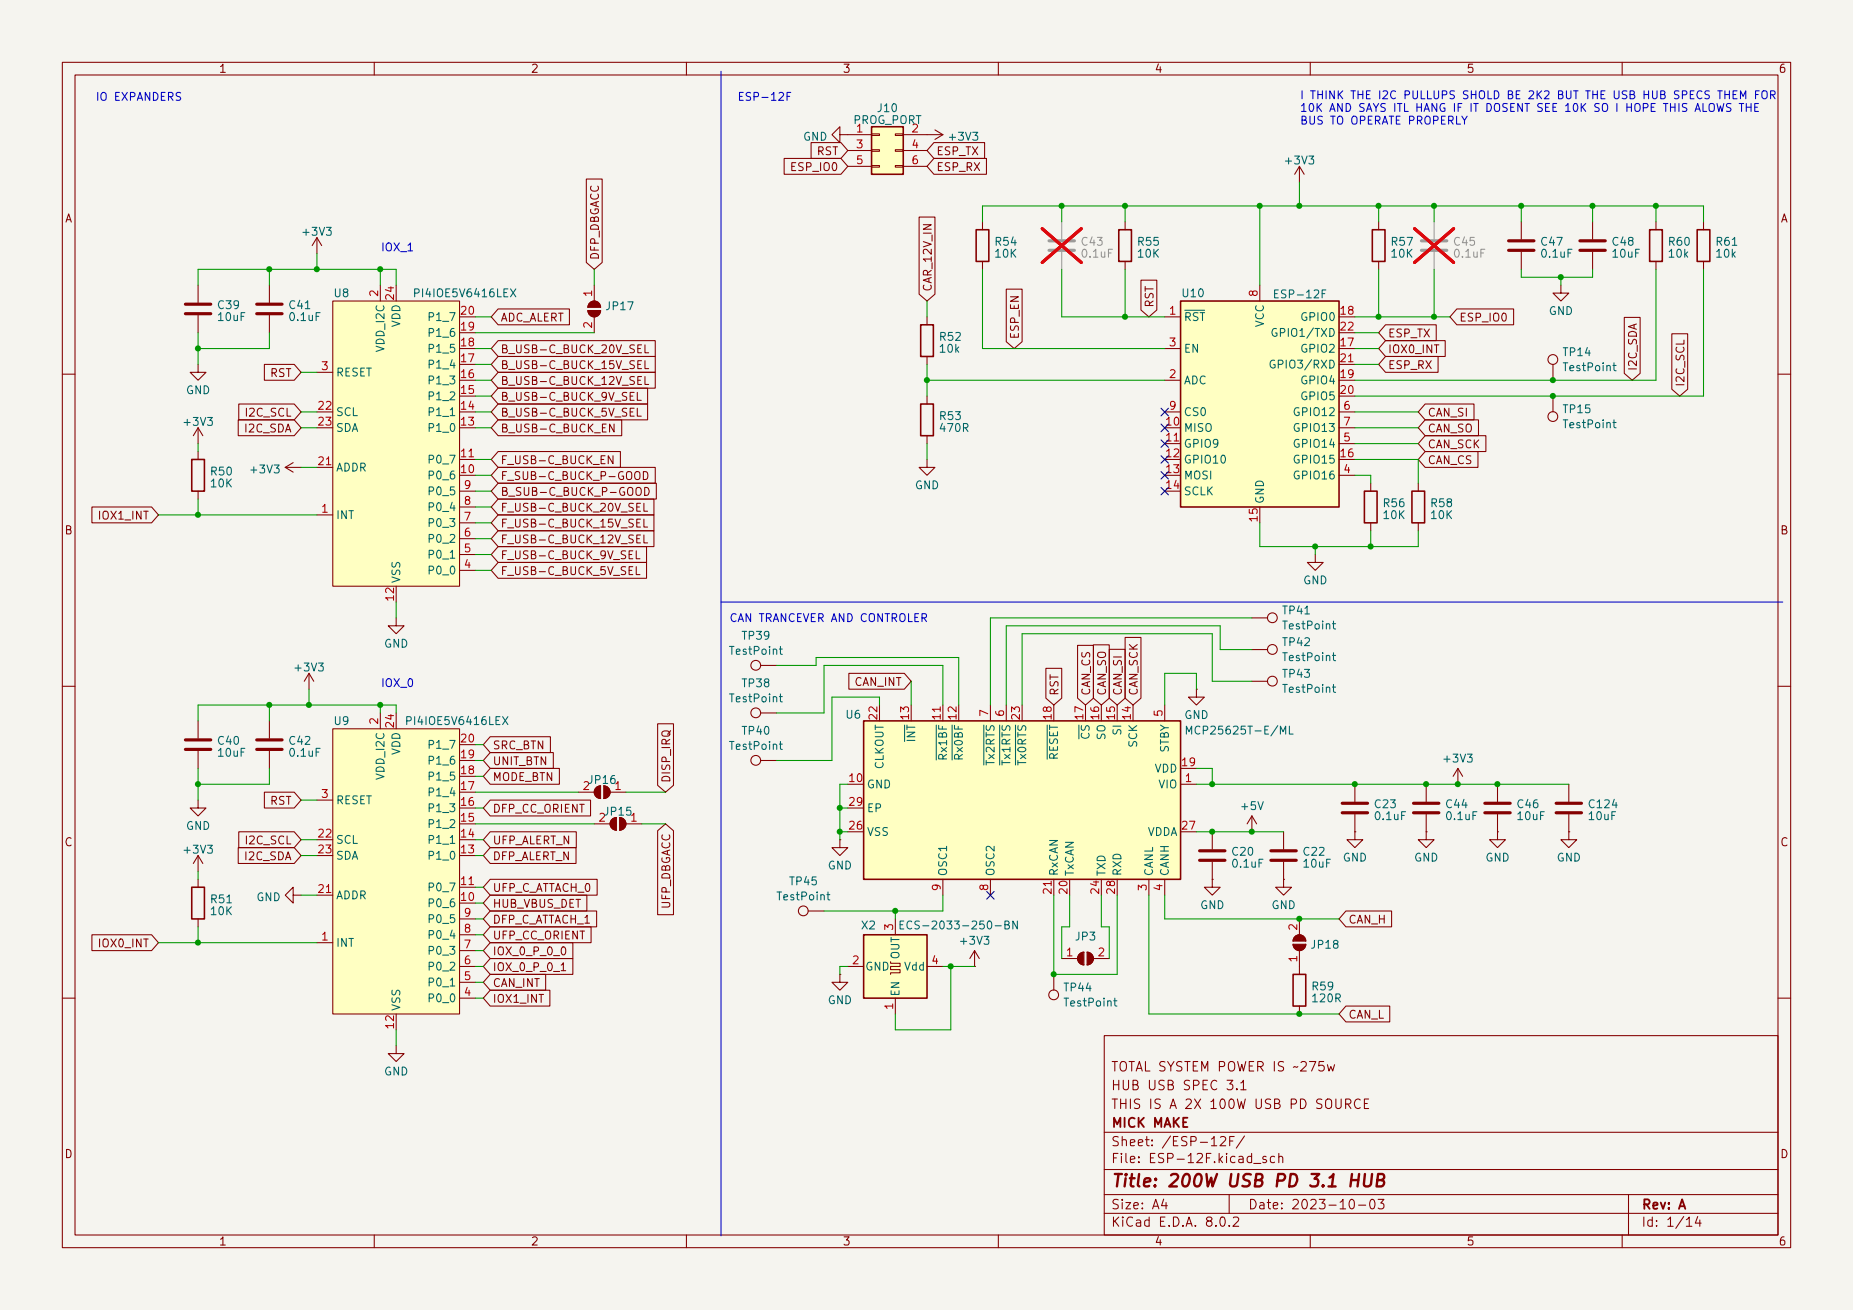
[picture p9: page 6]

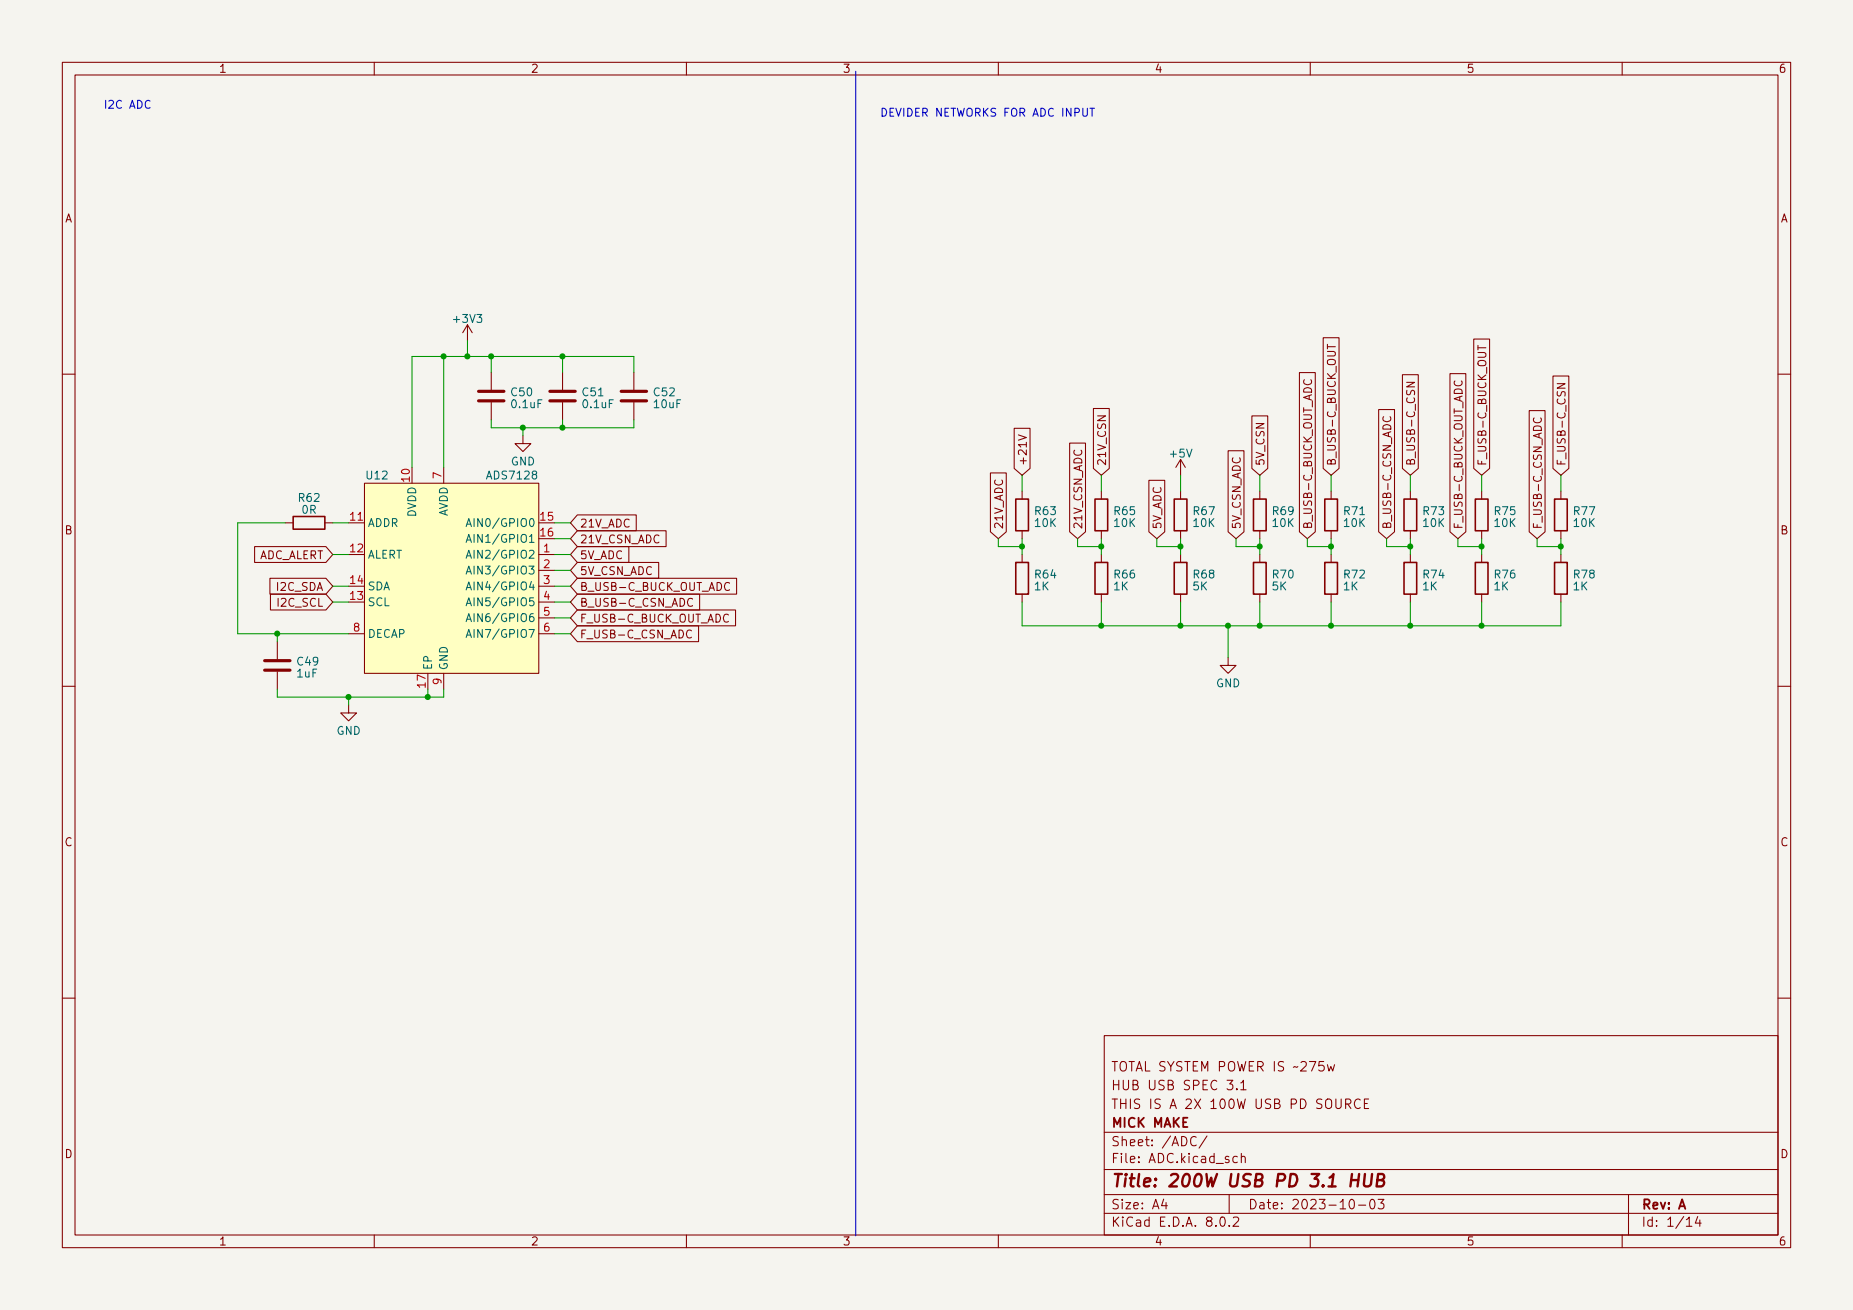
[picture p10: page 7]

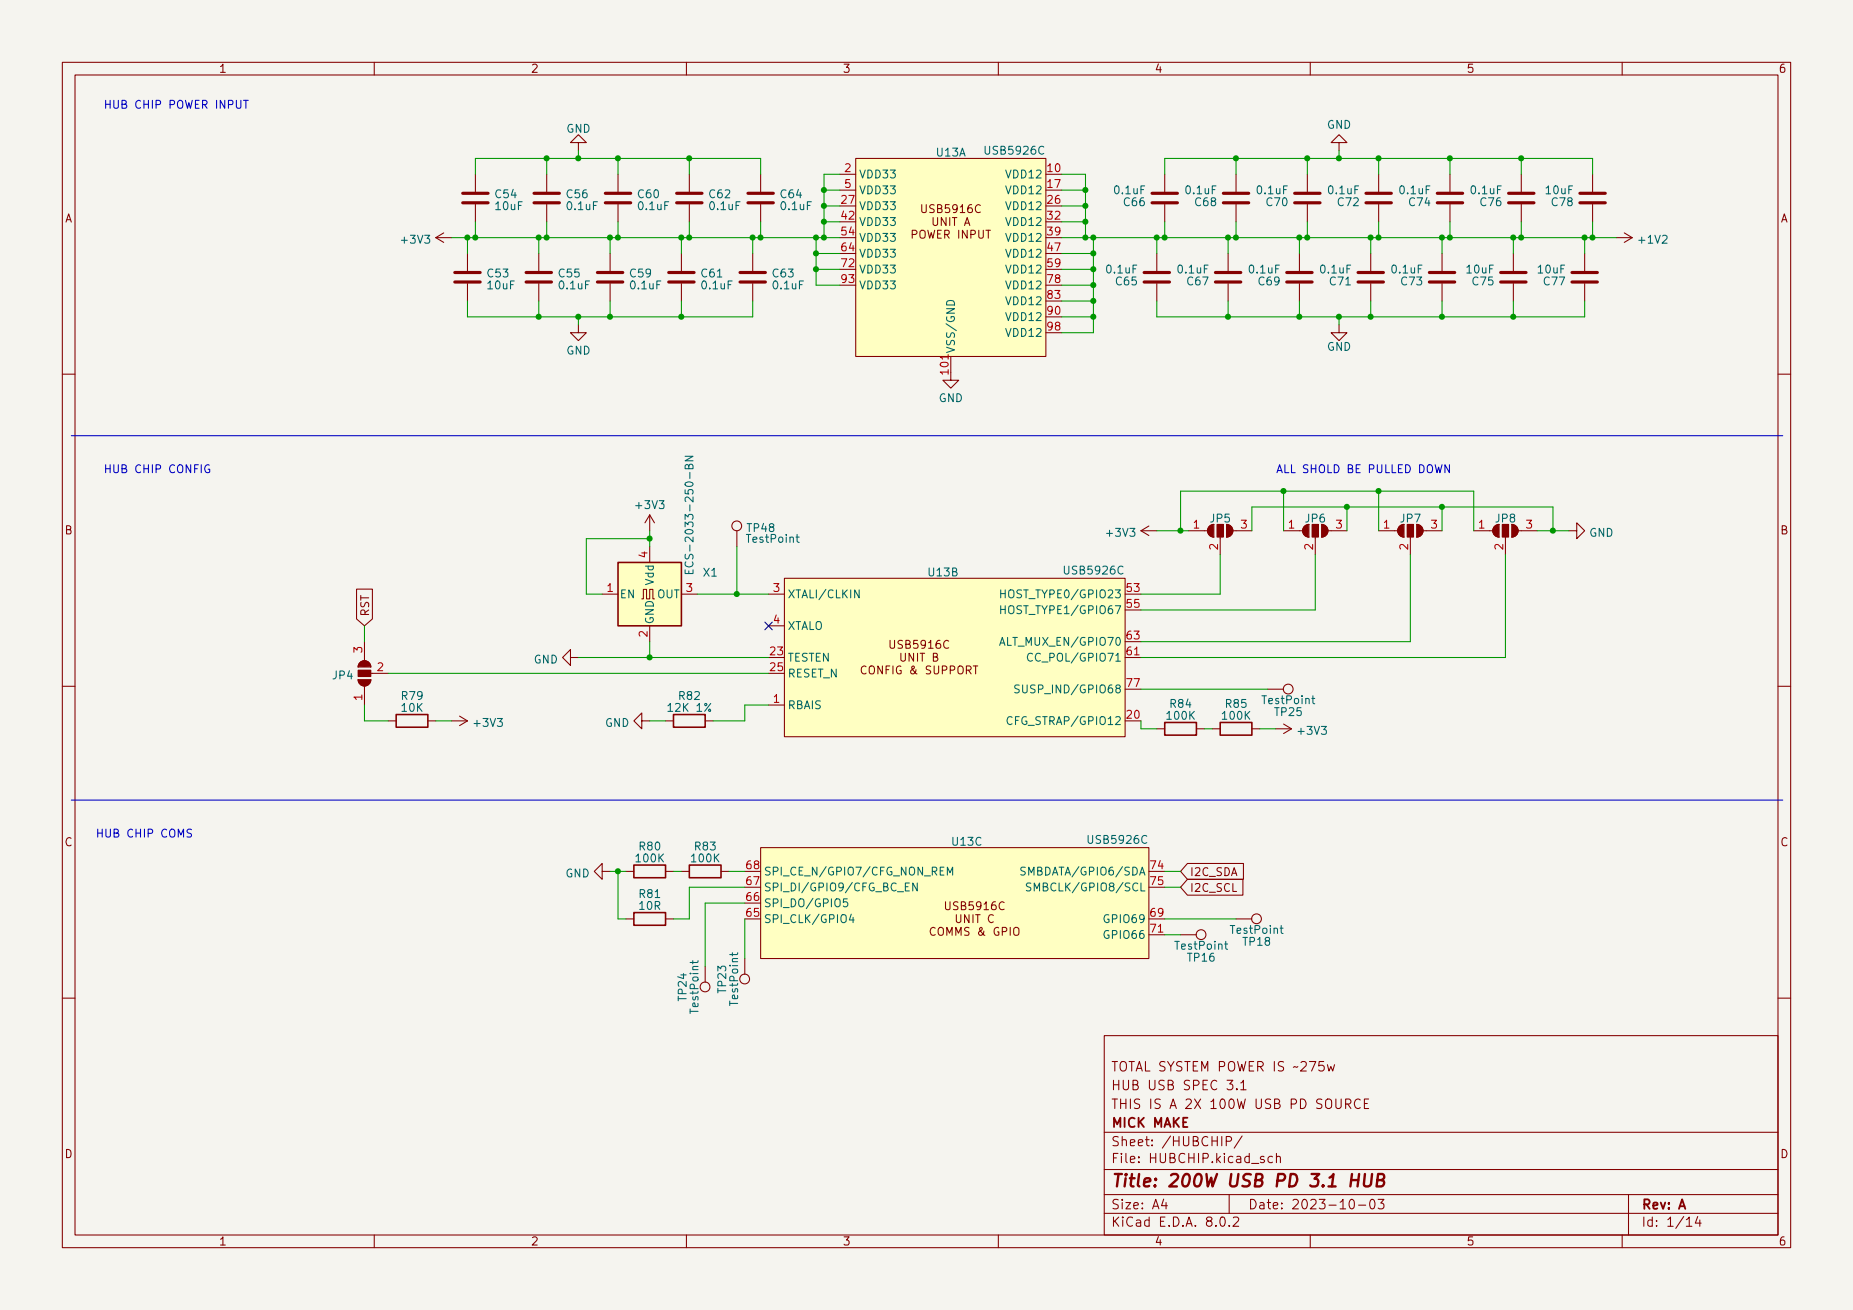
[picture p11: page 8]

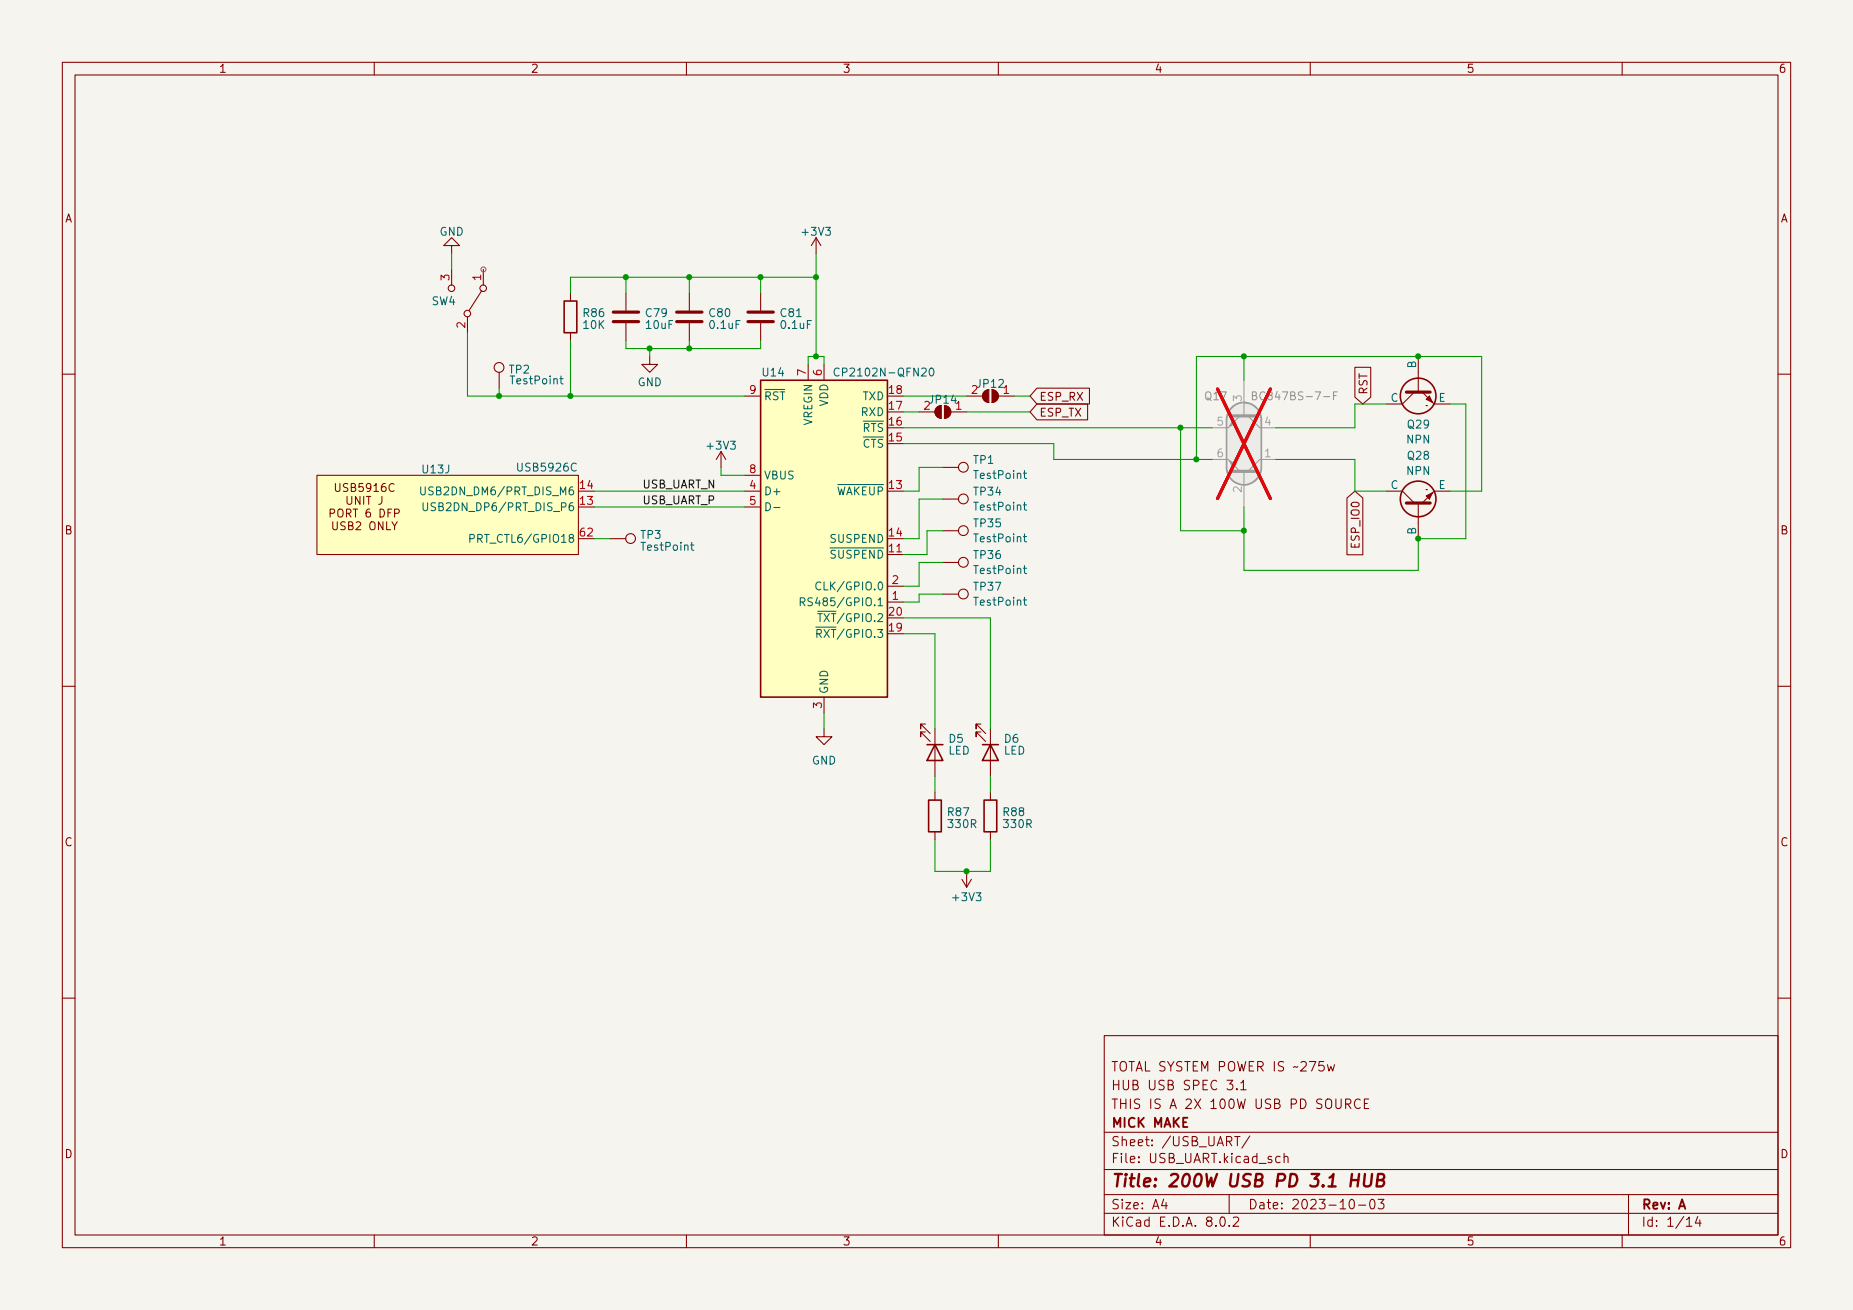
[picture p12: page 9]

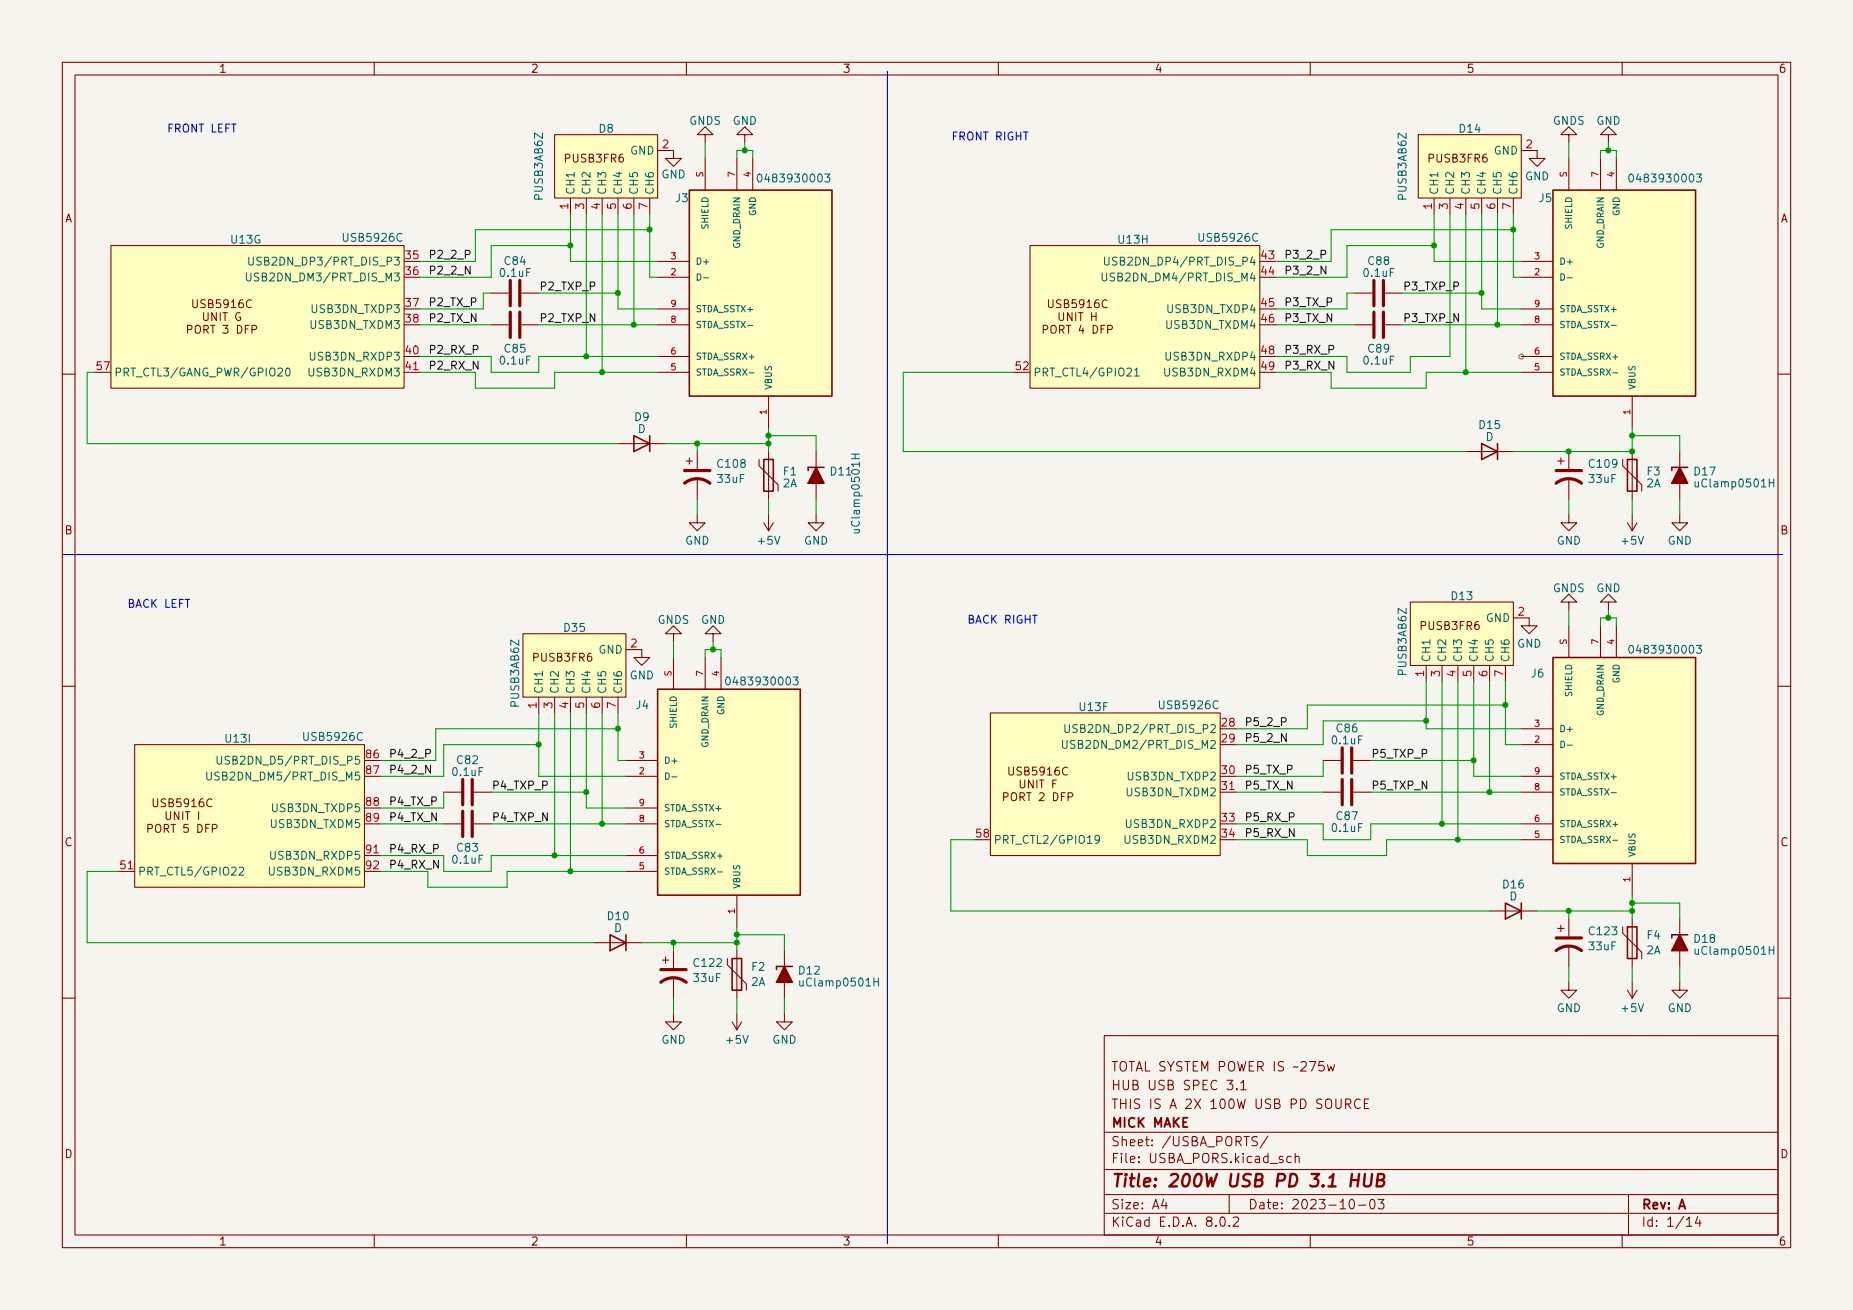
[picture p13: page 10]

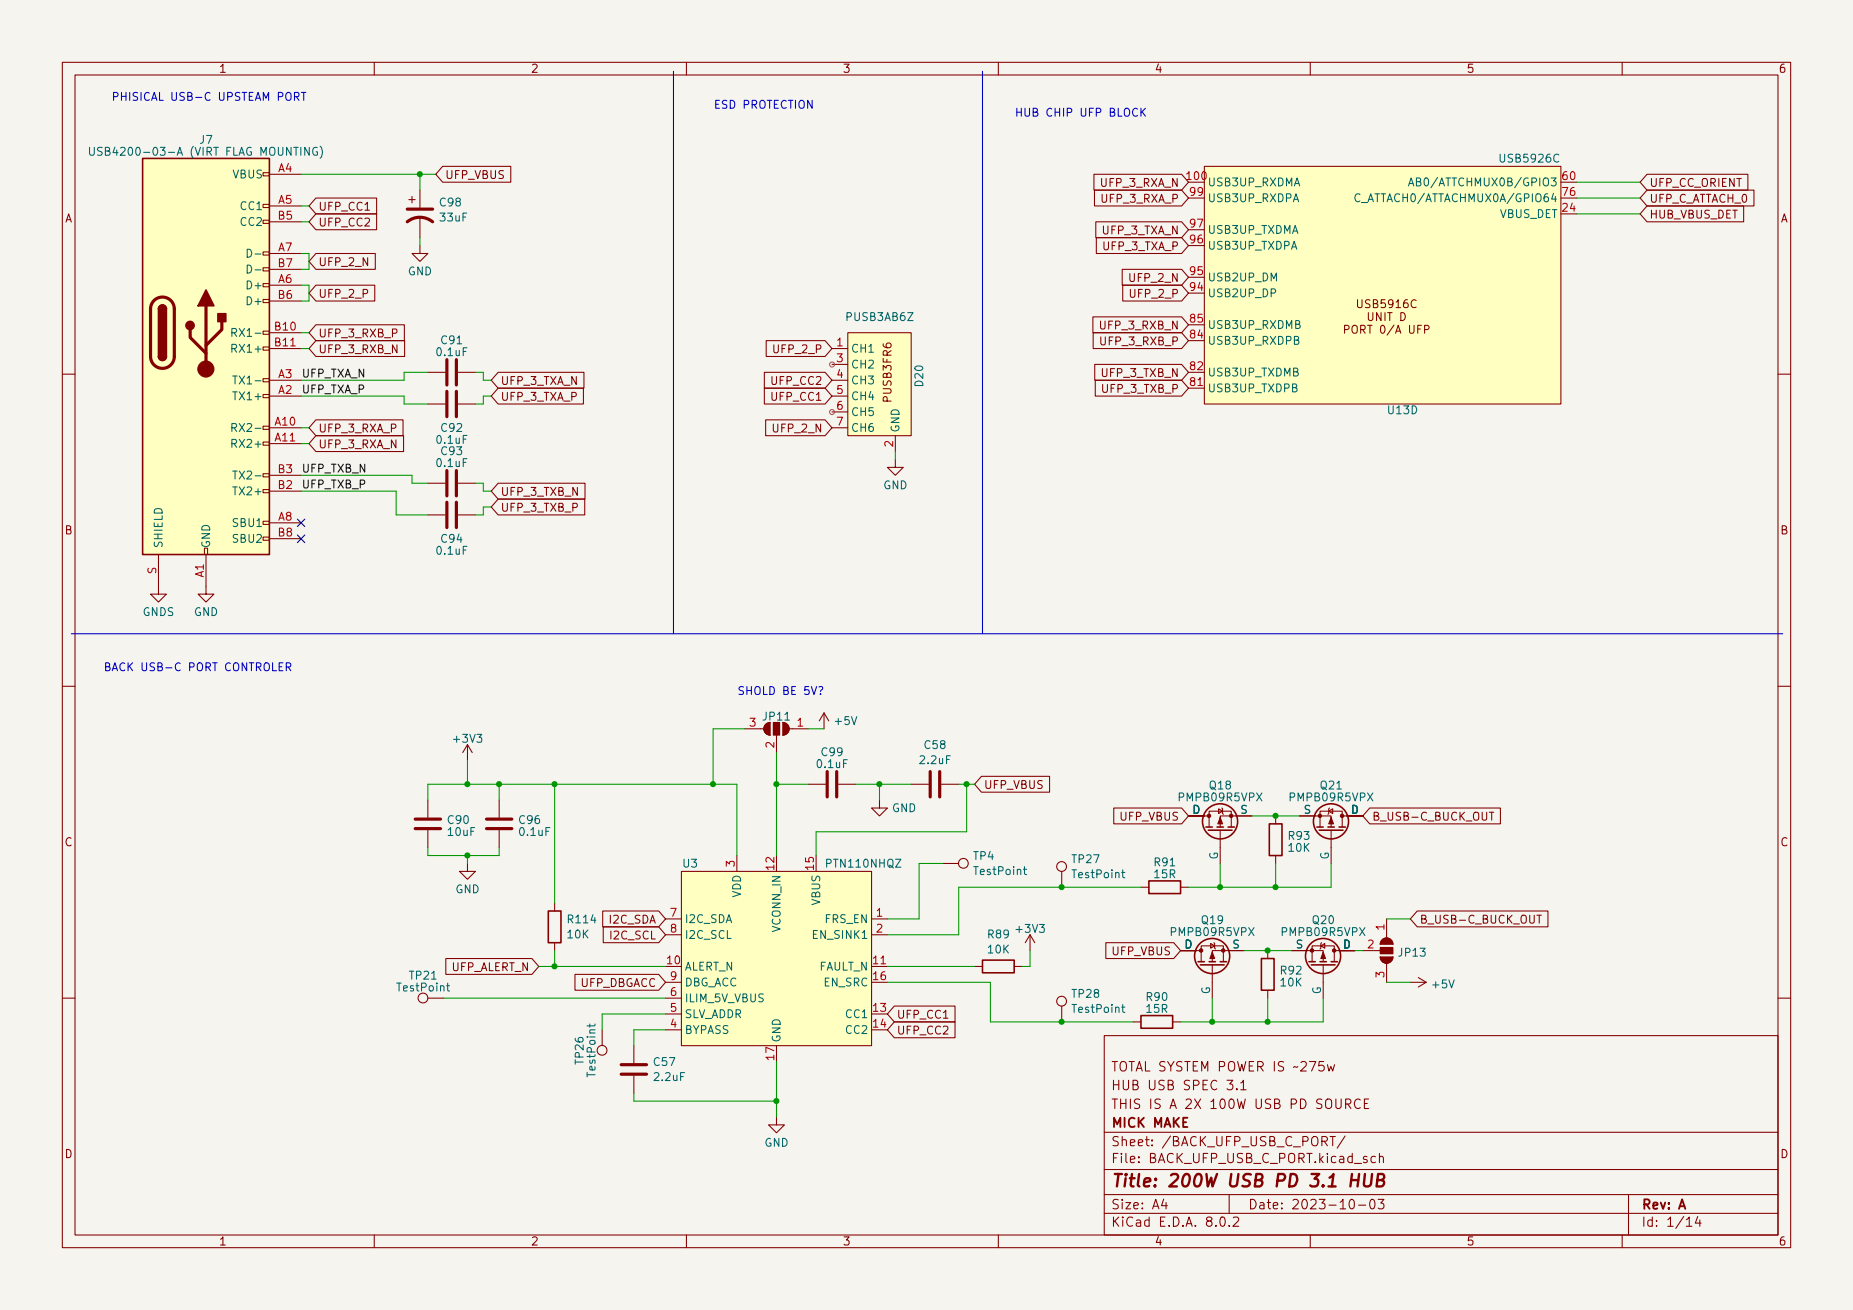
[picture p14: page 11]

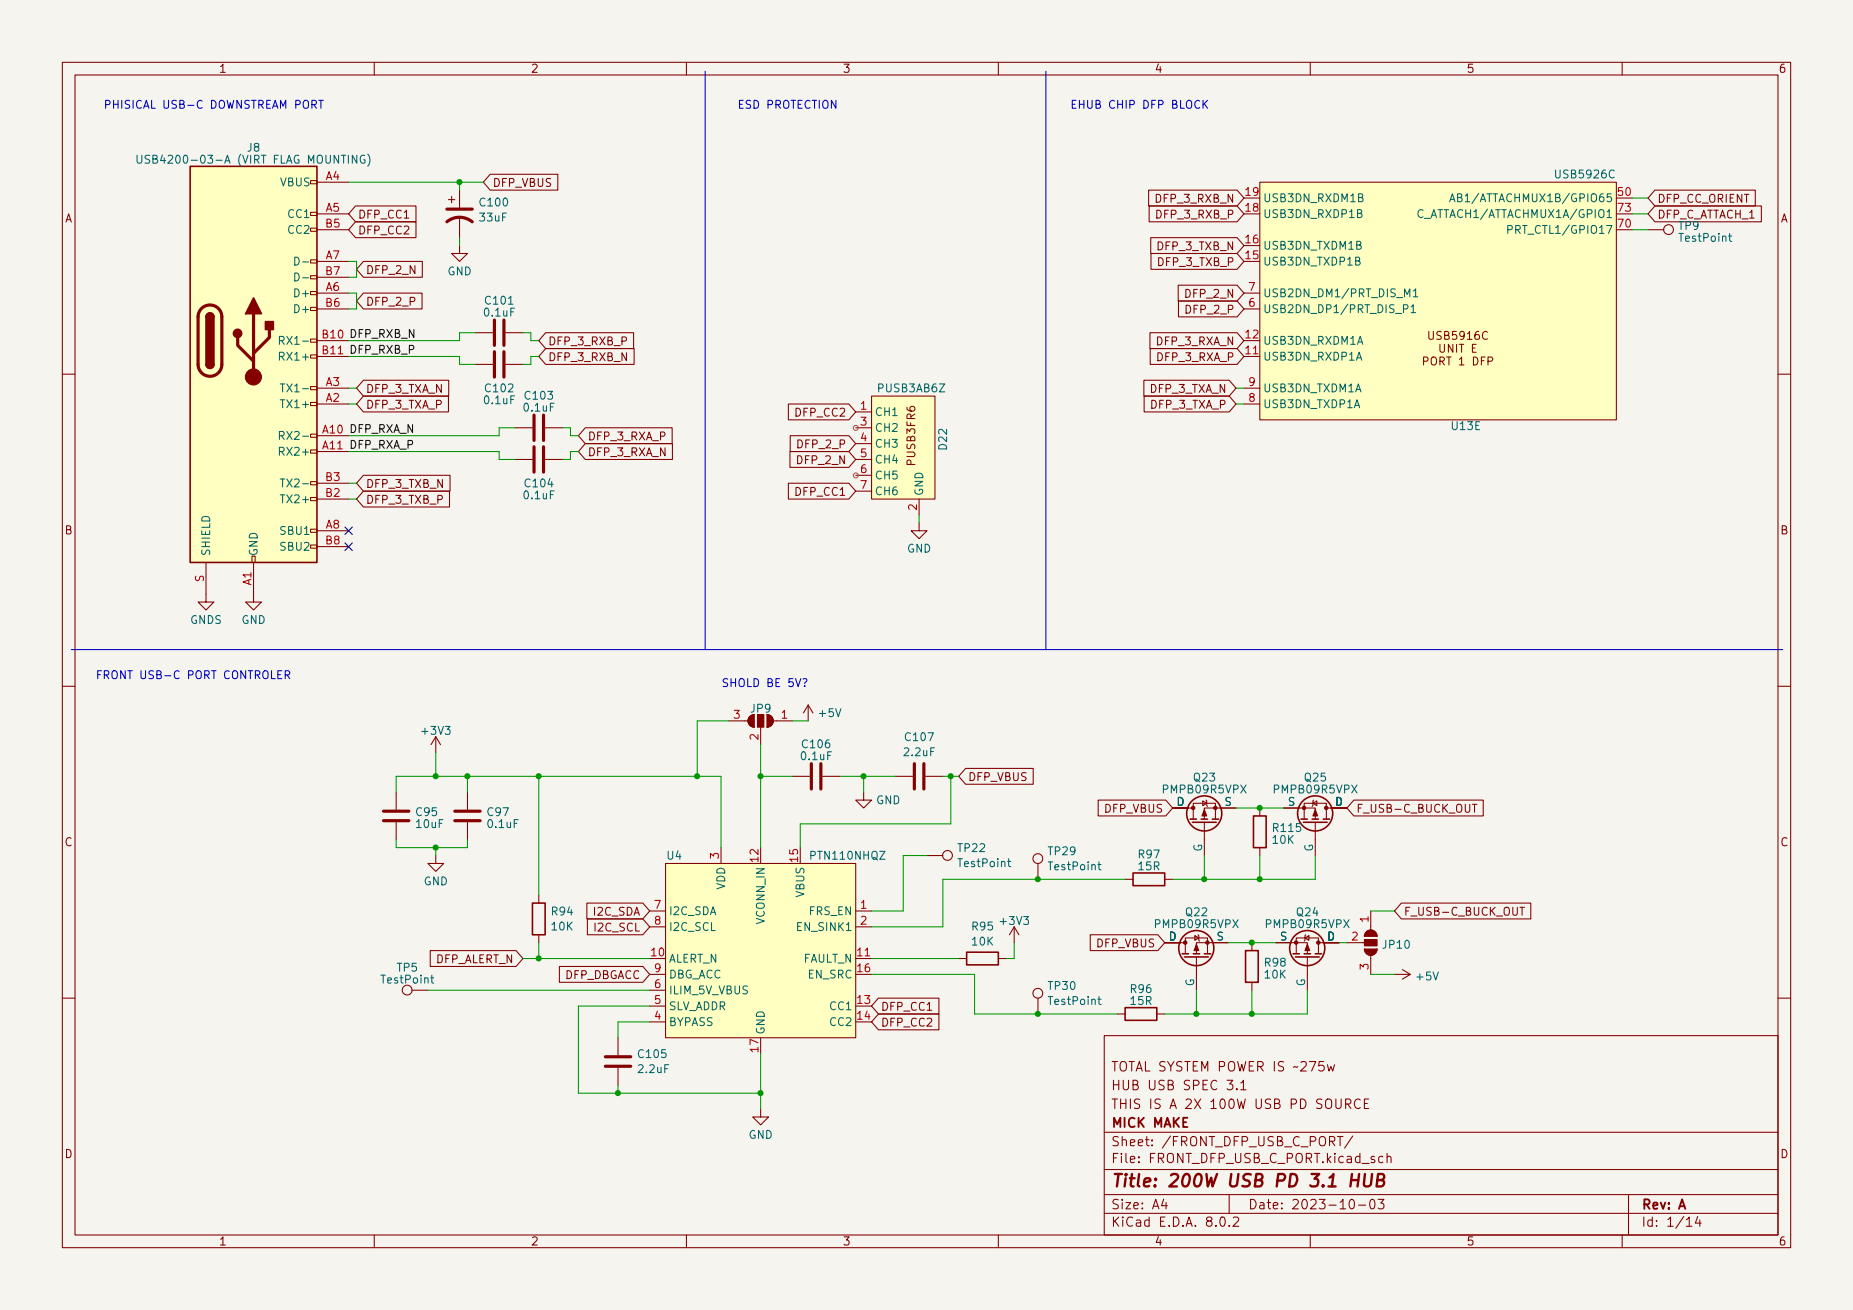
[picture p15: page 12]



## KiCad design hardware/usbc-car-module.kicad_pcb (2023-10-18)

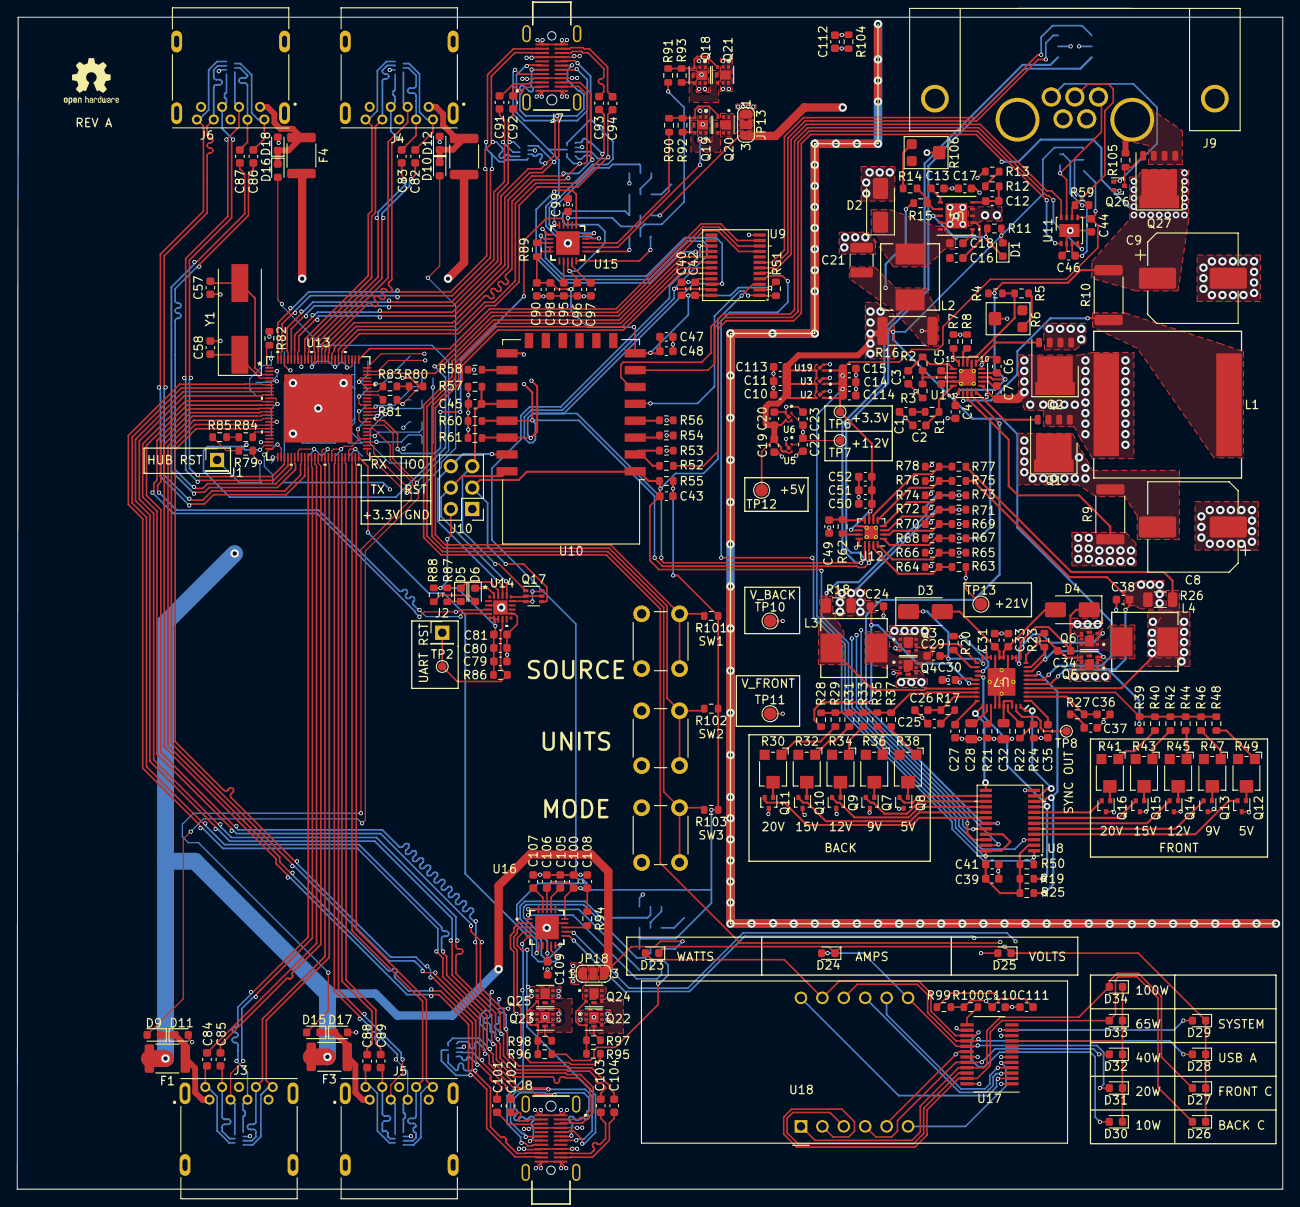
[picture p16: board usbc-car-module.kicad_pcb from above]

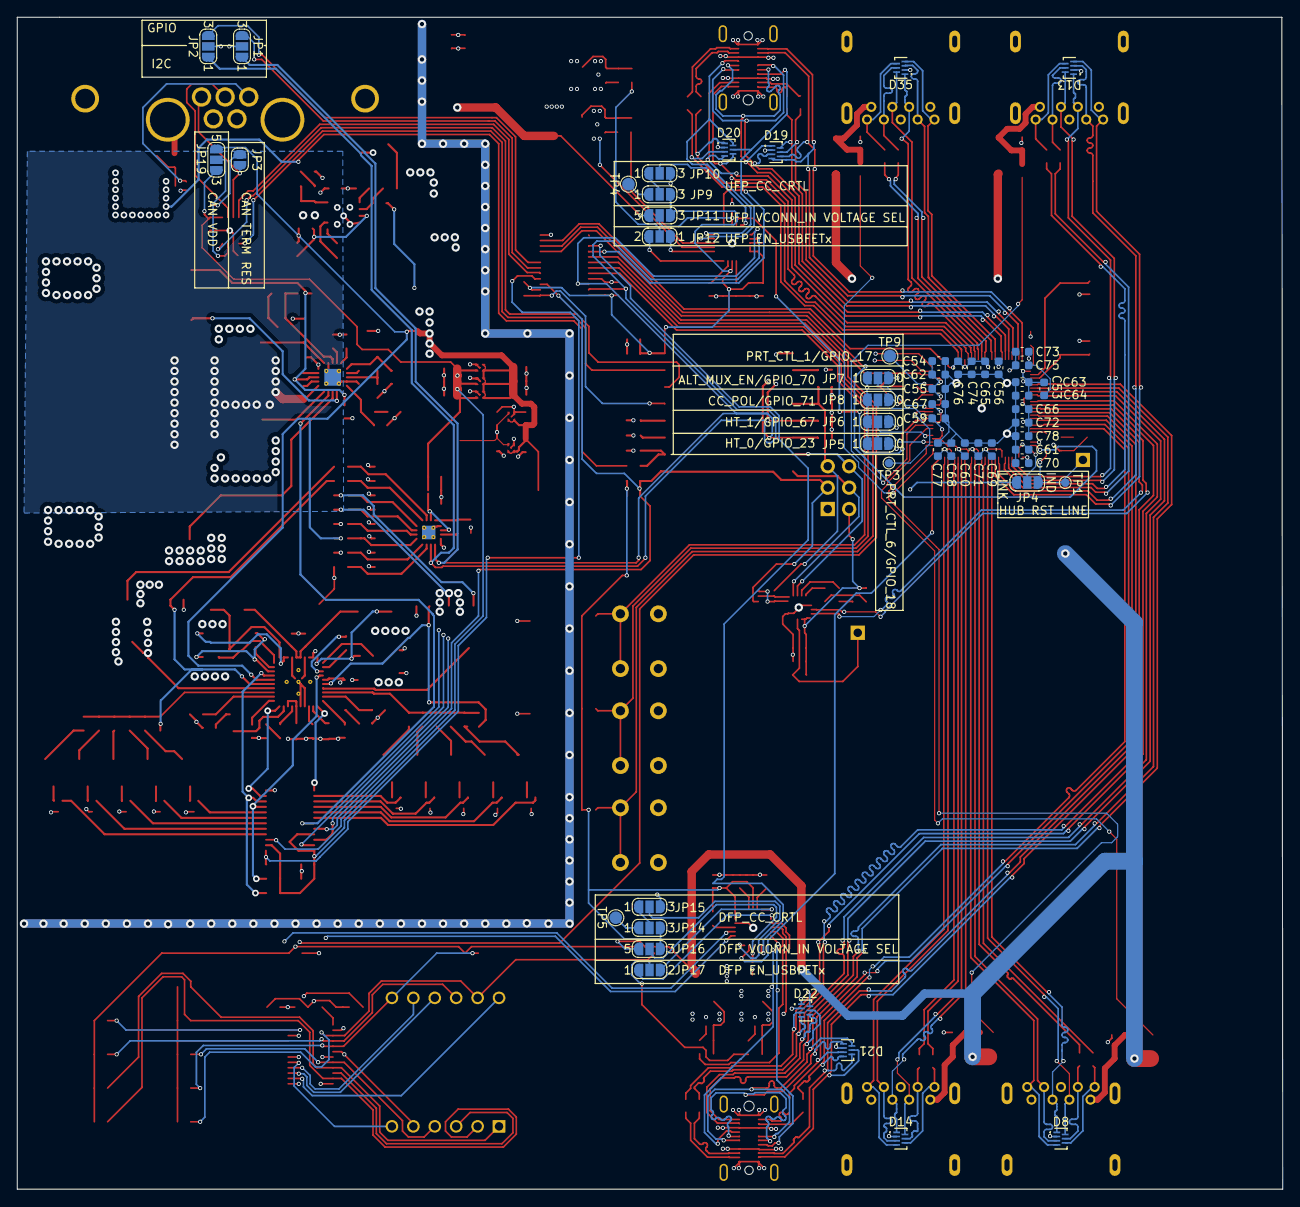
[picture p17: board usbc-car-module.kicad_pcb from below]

Board: 4 copper layers, 150.1 x 139.0 mm, 354 parts (54 on the bottom side), 290 nets.

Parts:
C1: 3uF3; C_0603_1608Metric
C2, C5, C7, C16, C18, C29, C34, C41, C42, C43, C44, C45, C46, C47, C50, C51, C55, C56, C59, C60, C61, C62, C63, C64, C65, C66, C67, C68, C69, C70, C71, C72, C73, C74, C76, C80, C81, C82, C83, C84, C85, C86, C87, C88, C89, C91, C92, C93, C94, C96, C98, C99, C101, C102, C103, C104, C106, C108, C109, C111, C112: 0.1uF; C_0603_1608Metric
C3, C4: 470pF; C_0603_1608Metric
C6, C17, C24, C25, C37, C38: 4.7uF; C_0603_1608Metric
C8: ouput cap EEEFK1V471SP 470uf; CP_Elec_10x10.5
C9: 120uF; CP_Elec_10x10.5
C10, C11, C13, C14, C15, C19, C20, C22, C23, C27, C35, C49, C113, C114: 1uF; C_0603_1608Metric
C12: 10pF; C_0603_1608Metric
C21: 15uF CGA6P3X7R1C156M250AB; C_1210_3225Metric
C26, C36, C57: 18pF; C_0603_1608Metric
C28, C32: 470nF; C_0805_2012Metric
C30: 50uF; C_0603_1608Metric
C31, C33, C95, C97, C105, C107: 2.2uF; C_0603_1608Metric
C39, C40, C48, C52, C53, C54, C75, C77, C78, C79, C90, C100, C110: 10uF; C_0603_1608Metric
C58: 18Pf; C_0603_1608Metric
D1, D5, D6: LED; D_0603_1608Metric
D2: SK510A-LTP; D_SMA
D3, D4: D_Shockley; D_SMA
D8, D13, D14, D19, D20, D21, D22, D35: PUSB3AB6Z_NEX
D9, D10, D15, D16: D; D_0603_1608Metric
D11, D12, D17, D18: uClamp0501H; D_0603_1608Metric
D23: W; D_0603_1608Metric
D24: A; D_0603_1608Metric
D25: V; D_0603_1608Metric
D26: BACK USBC POWER; D_0603_1608Metric
D27: FRONT USBC POWER; D_0603_1608Metric
D28: USBA POWER; D_0603_1608Metric
D29: TOTAL SYSTEM POWER; D_0603_1608Metric
D30: 10W; D_0603_1608Metric
D31: 20W; D_0603_1608Metric
D32: 40W; D_0603_1608Metric
D33: 65W; D_0603_1608Metric
D34: 100W; D_0603_1608Metric
F1, F3: 2A; Fuse_1812_4532Metric
F2, F4: 1A; Fuse_1812_4532Metric
J1, J2: PinHeader_1x01_P2.54mm_Vertical
J3, J4, J5, J6: 0483930003; MOLEX_0483930003
J7, J8: USB4200-03-A (VIRT FLAG MOUNTING); USB4200-03-A_REVA
J9: 684M7W2103L461
J10: PROG_PORT; PinHeader_2x03_P2.54mm_Vertical
JP1, JP2, JP4, JP5, JP6, JP7, JP8, JP9, JP10, JP11, JP12, JP13, JP14, JP15, JP16, JP17, JP18, JP19: SolderJumper-3_P1.3mm_Open_RoundedPad1.0x1.5mm_NumberLabels
JP3: SolderJumper-2_P1.3mm_Open_RoundedPad1.0x1.5mm
L1: IHLP6767GZER1R0M01; IND-6767GZ_VIS
L2: 1.2uH CR75NP-1R2MC; IND25X25CZ
L3, L4: IHLP2525CZER2R2M01; IND25X25CZ
Q1, Q2: NMOS; PQFN-8-EP_6x5mm_P1.27mm_Generic
Q3, Q4, Q5, Q6: PMPB11EN,115; TRANS_PMPB11EN_115
Q7, Q8, Q9, Q10, Q11, Q12, Q13, Q14, Q15, Q16, Q26: NMOS; SOT-416
Q17: BC847BS-7-F; SOT-363_SC-70-6
Q18, Q19, Q20, Q21, Q22, Q23, Q24, Q25: PMOS; TRANS_PMPB11EN_115
Q27: AON7421; PQFN-8-EP_6x5mm_P1.27mm_Generic
R1: 35K; R_0603_1608Metric
R2: 20K; R_0603_1608Metric
R3, R5, R7, R11, R12, R14, R22, R28, R33, R35, R39, R44, R46, R50, R51, R54, R55, R56, R57, R58, R63, R65, R67, R69, R71, R73, R75, R77, R79, R86, R89, R92, R93, R94, R97, R98, R99, R100, R101, R102, R103: 10K; R_0603_1608Metric
R4, R19, R25, R80, R83, R84, R85, R105: 100K; R_0603_1608Metric
R6, R106: 1K; Potentiometer_Bourns_TC33X_Vertical
R8, R21, R62: 0R; R_0603_1608Metric
R9, R10, R16: 1.5mR; R_2512_6332Metric
R13, R64, R66, R72, R74, R76, R78: 1K; R_0603_1608Metric
R15: 56K; R_0603_1608Metric
R17, R27: 5.9K; R_0603_1608Metric
R18, R26: 10mR; R_1206_3216Metric
R20: RHO1; R_0603_1608Metric
R23: RHO2; R_0603_1608Metric
R24, R53: 470R; R_0603_1608Metric
R29, R40: 30K; R_0603_1608Metric
R30, R32, R34, R36, R38, R41, R43, R45, R47, R49: 10K; Potentiometer_Bourns_TC33X_Vertical
R31, R42: 22K; R_0603_1608Metric
R37, R48, R68, R70: 5K; R_0603_1608Metric
R52, R60, R61: 10k; R_0603_1608Metric
R59: 120R; R_0603_1608Metric
R81: 10R; R_0603_1608Metric
R82: 12K 1%; R_0603_1608Metric
R87, R88, R104: 330R; R_0603_1608Metric
R90, R91, R95, R96: 15R; R_0603_1608Metric
SW1, SW2, SW3: SW_Push; SW_PUSH_6mm
TP1, TP3, TP6, TP7, TP8: TestPoint; TestPoint_Pad_D1.0mm
TP2: TestPoint_Pad_D1.0mm
TP4, TP5, TP9, TP10, TP11, TP12, TP13: TestPoint; TestPoint_Pad_D1.5mm
U1: LM51231-Q1; QFN-20-1EP_3.5x3.5mm_P0.5mm_EP2x2mm_ThermalVias
U2, U3, U19: NCP177BMX330TCG; VREG_NCP170AMX300TCG
U4: LMR14050-Q1; LMR14050
U5, U6: NCP177AMX120TCG; VREG_NCP170AMX300TCG
U7: LM5143
U8, U9: PI4IOE5V6416LEX; TSSOP-24_4.4x7.8mm_P0.65mm
U10: ESP-12F; ESP-12E
U11: MCP2558FD-xMF; DFN-8-1EP_3x3mm_P0.65mm_EP1.55x2.4mm
U12: WQFN-16-1EP_3x3mm_P0.5mm_EP1.6x1.6mm_ThermalVias
U13: VQFN100_KD_MCH
U14: CP2102N-QFN20; QFN20_SIL
U15, U16: PTN5100BSMP
U17: AS1115-BSST; QSOP-24_3.9x8.7mm_P0.635mm
U18: LTC-5723HR; CA56-12CGKWA
Y1: 25MHz; Crystal_SMD_HC49-SD

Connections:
5V_ADC: R67.2, R68.1, U12.1 (AIN2/GPIO2)
5V_CSN: C21.1, L2.2, R15.2, R16.1, R69.1
5V_CSN_ADC: R69.2, R70.1, U12.2 (AIN3/GPIO3)
21V_ADC: R63.2, R64.1, U12.15 (AIN0/GPIO0)
21V_COMP: C2.1, R1.1, U1.20 (COMP)
21V_CSN: C8.2, Q1.5 (D), R9.1, R65.1
21V_CSN_ADC: R65.2, R66.1, U12.16 (AIN1/GPIO1)
21V_PGOOD: U1.4 (PGOOD), U8.19 (P1_6)
+1V2: C22.1, C23.1, C65.2, C66.1, C67.2, C68.1, C69.2, C70.1, C71.2, C72.1, C73.2, C74.1, C75.2, C76.1, C77.2, C78.1, TP7.1, U5.1 (OUT), U6.1 (OUT), U13.10 (VDD12), U13.17 (VDD12), U13.26 (VDD12), U13.32 (VDD12), U13.39 (VDD12), U13.47 (VDD12), U13.59 (VDD12), U13.78 (VDD12), U13.83 (VDD12), U13.90 (VDD12), U13.98 (VDD12)
+3V3: C14.1, C15.1, C39.1, C40.1, C41.1, C42.1, C43.1, C44.2, C45.1, C47.1, C48.1, C50.1, C51.1, C52.1, C53.1, C54.2, C55.1, C56.2, C59.1, C60.2, C61.1, C62.2, C63.1, C64.2, C79.1, C80.1, C81.1, C90.1, C96.1, C98.1, C100.1, C106.1, C108.1, C110.1, C111.1, C114.1, J10.2, JP5.1 (A), JP6.1 (A), JP7.1 (A), JP8.1 (A), JP9.3 (B), JP11.3 (B), JP14.3 (B), JP16.3 (B), JP19.1 (A), R19.1, R25.2, R50.1, R51.1, R54.1, R55.1, R57.1, R60.1, R61.1, R79.2, R85.2, R86.1, R87.2, R88.2, R89.2, R94.2, R99.1, R100.1, R101.1, R102.1, R103.1, TP6.1, U2.1 (OUT), U3.1 (OUT), U8.2 (VDD_I2C), U8.21 (ADDR), U8.24 (VDD), U9.2 (VDD_I2C), U9.24 (VDD), U10.8 (VCC), U11.5 (VIO), U12.7 (AVDD), U12.10 (DVDD), U13.2 (VDD33), U13.5 (VDD33), U13.27 (VDD33), U13.42 (VDD33), U13.54 (VDD33), U13.64 (VDD33), U13.72 (VDD33), U13.93 (VDD33), U14.6 (VDD), U14.7 (VREGIN), U14.8 (VBUS), U15.14 (SLV_ADDR), U15.15 (VDD), U15.18 (VIO), U16.15 (VDD), U16.18 (VIO), U17.19 (VDD), U19.1 (OUT)
+5V: C10.1, C11.1, C19.1, C20.1, C113.1, D1.2 (A), F1.2, F2.2, F3.2, F4.2, JP11.1 (A), JP13.3 (B), JP16.1 (A), JP18.3 (B), JP19.3 (B), R11.1, R16.2, R67.1, TP12.1, U2.3 (EN), U2.4 (IN), U3.3 (EN), U3.4 (IN), U5.3 (EN), U5.4 (IN), U6.3 (EN), U6.4 (IN), U7.6 (VCCX), U19.3 (EN), U19.4 (IN)
+21V: C16.1, C17.1, C30.2, Q3.1 (D), Q3.2 (D), Q3.5 (D), Q3.6 (D), Q3.7 (D), Q5.1 (D), Q5.2 (D), Q5.5 (D), Q5.6 (D), Q5.7 (D), R9.2, R63.1, TP13.1, U1.3 (VOUT/SENSE), U4.2 (VIN), U4.3 (VIN), U4.4 (EN), U7.25 (VIN)
/5V USB-A AND MCU POWER/5V_BOOT: C18.1, U4.1 (BOOT)
/5V USB-A AND MCU POWER/5V_FB: R14.2, R15.1, U4.7 (FB)
/5V USB-A AND MCU POWER/5V_RT: R12.2, R13.1
/5V USB-A AND MCU POWER/5V_SS: C13.1, U4.6 (SS)
/5V USB-A AND MCU POWER/5V_SW: C18.2, D2.1 (K), L2.1, U4.10 (SW)
/12-21V INPUT BOOST CONVERTER/21V_COMP_1: C1.1, R1.2
/12-21V INPUT BOOST CONVERTER/21V_VCC: C6.1, U1.9 (VCC)
/12-21V INPUT BOOST CONVERTER/CSN: L1.2, R10.1, U1.2 (CSN)
/12-21V INPUT BOOST CONVERTER/HB: C7.1, U1.7 (HB)
/12-21V INPUT BOOST CONVERTER/HI_SW: Q1.4 (G), U1.5 (HO)
/12-21V INPUT BOOST CONVERTER/LO_SW: Q2.4 (G), U1.11 (LO)
/12-21V INPUT BOOST CONVERTER/RT: R7.2, U1.15 (RT)
/12-21V INPUT BOOST CONVERTER/SS: C5.2, U1.17 (SS)
/12-21V INPUT BOOST CONVERTER/SW: C7.2, L1.1, Q1.1 (S), Q1.2 (S), Q1.3 (S), Q2.5 (D), U1.6 (SW)
/12-21V INPUT BOOST CONVERTER/TRK: R2.2, R3.1, U1.18 (TRK)
/12-21V INPUT BOOST CONVERTER/UVLO/EN: R4.2, R5.1, U1.13 (UVLO/EN)
/12-21V INPUT BOOST CONVERTER/VREF: C3.1, R2.1, U1.16 (VREF/RANGE)
/BACK_UFP_USB_C_PORT/UFP_TXA_N: C91.1, J7.A3 (TX1-)
/BACK_UFP_USB_C_PORT/UFP_TXA_P: C92.2, J7.A2 (TX1+)
/BACK_UFP_USB_C_PORT/UFP_TXB_N: C93.1, J7.B3 (TX2-)
/BACK_UFP_USB_C_PORT/UFP_TXB_P: C94.2, J7.B2 (TX2+)
/FRONT_DFP_USB_C_PORT/DFP_RXA_N: C103.1, J8.A10 (RX2-)
/FRONT_DFP_USB_C_PORT/DFP_RXA_P: C104.2, J8.A11 (RX2+)
/FRONT_DFP_USB_C_PORT/DFP_RXB_N: C101.1, J8.B10 (RX1-)
/FRONT_DFP_USB_C_PORT/DFP_RXB_P: C102.2, J8.B11 (RX1+)
/USBA_PORTS/P2_2_N: D8.7 (CH6), J3.2 (D-), U13.36 (USB2DN_DM3/PRT_DIS_M3)
/USBA_PORTS/P2_2_P: D8.1 (CH1), J3.3 (D+), U13.35 (USB2DN_DP3/PRT_DIS_P3)
/USBA_PORTS/P2_RX_N: D8.4 (CH3), J3.5 (STDA_SSRX-), U13.41 (USB3DN_RXDM3)
/USBA_PORTS/P2_RX_P: D8.3 (CH2), J3.6 (STDA_SSRX+), U13.40 (USB3DN_RXDP3)
/USBA_PORTS/P2_TXP_N: C85.1, D8.6 (CH5), J3.8 (STDA_SSTX-)
/USBA_PORTS/P2_TXP_P: C84.2, D8.5 (CH4), J3.9 (STDA_SSTX+)
/USBA_PORTS/P2_TX_N: C85.2, U13.38 (USB3DN_TXDM3)
/USBA_PORTS/P2_TX_P: C84.1, U13.37 (USB3DN_TXDP3)
/USBA_PORTS/P3_2_N: D14.7 (CH6), J5.2 (D-), U13.44 (USB2DN_DM4/PRT_DIS_M4)
/USBA_PORTS/P3_2_P: D14.1 (CH1), J5.3 (D+), U13.43 (USB2DN_DP4/PRT_DIS_P4)
/USBA_PORTS/P3_RX_N: D14.4 (CH3), J5.5 (STDA_SSRX-), U13.49 (USB3DN_RXDM4)
/USBA_PORTS/P3_RX_P: D14.3 (CH2), J5.6 (STDA_SSRX+), U13.48 (USB3DN_RXDP4)
/USBA_PORTS/P3_TXP_N: C89.1, D14.6 (CH5), J5.8 (STDA_SSTX-)
/USBA_PORTS/P3_TXP_P: C88.2, D14.5 (CH4), J5.9 (STDA_SSTX+)
/USBA_PORTS/P3_TX_N: C89.2, U13.46 (USB3DN_TXDM4)
/USBA_PORTS/P3_TX_P: C88.1, U13.45 (USB3DN_TXDP4)
/USBA_PORTS/P4_2_N: D35.7 (CH6), J4.2 (D-), U13.87 (USB2DN_DM5/PRT_DIS_M5)
/USBA_PORTS/P4_2_P: D35.1 (CH1), J4.3 (D+), U13.86 (USB2DN_D5/PRT_DIS_P5)
/USBA_PORTS/P4_RX_N: D35.4 (CH3), J4.5 (STDA_SSRX-), U13.92 (USB3DN_RXDM5)
/USBA_PORTS/P4_RX_P: D35.3 (CH2), J4.6 (STDA_SSRX+), U13.91 (USB3DN_RXDP5)
/USBA_PORTS/P4_TXP_N: C83.1, D35.6 (CH5), J4.8 (STDA_SSTX-)
/USBA_PORTS/P4_TXP_P: C82.2, D35.5 (CH4), J4.9 (STDA_SSTX+)
/USBA_PORTS/P4_TX_N: C83.2, U13.89 (USB3DN_TXDM5)
/USBA_PORTS/P4_TX_P: C82.1, U13.88 (USB3DN_TXDP5)
/USBA_PORTS/P5_2_N: D13.7 (CH6), J6.2 (D-), U13.29 (USB2DN_DM2/PRT_DIS_M2)
/USBA_PORTS/P5_2_P: D13.1 (CH1), J6.3 (D+), U13.28 (USB2DN_DP2/PRT_DIS_P2)
/USBA_PORTS/P5_RX_N: D13.4 (CH3), J6.5 (STDA_SSRX-), U13.34 (USB3DN_RXDM2)
/USBA_PORTS/P5_RX_P: D13.3 (CH2), J6.6 (STDA_SSRX+), U13.33 (USB3DN_RXDP2)
/USBA_PORTS/P5_TXP_N: C87.1, D13.6 (CH5), J6.8 (STDA_SSTX-)
/USBA_PORTS/P5_TXP_P: C86.2, D13.5 (CH4), J6.9 (STDA_SSTX+)
/USBA_PORTS/P5_TX_N: C87.2, U13.31 (USB3DN_TXDM2)
/USBA_PORTS/P5_TX_P: C86.1, U13.30 (USB3DN_TXDP2)
/USB_UART/USB_UART_N: U13.14 (USB2DN_DM6/PRT_DIS_M6), U14.5 (D-)
/USB_UART/USB_UART_P: U13.13 (USB2DN_DP6/PRT_DIS_P6), U14.4 (D+)
ADC_ALERT: U8.20 (P1_7), U12.12 (ALERT)
B_SUB-C_BUCK_P-GOOD: R19.2, U7.24 (PG1), U8.9 (P0_5)
B_USB-C_BUCK_5V_SEL: Q8.2 (G), U8.14 (P1_1)
B_USB-C_BUCK_9V_SEL: Q7.2 (G), U8.15 (P1_2)
B_USB-C_BUCK_12V_SEL: Q9.2 (G), U8.16 (P1_3)
B_USB-C_BUCK_15V_SEL: Q10.2 (G), U8.17 (P1_4)
B_USB-C_BUCK_20V_SEL: Q11.2 (G), U8.18 (P1_5)
B_USB-C_BUCK_EN: U7.31 (EN1), U8.13 (P1_0)
B_USB-C_BUCK_FB: R28.2, R29.1, R31.1, R33.1, R35.1, R37.1, U7.28 (FB1)
B_USB-C_BUCK_OUT: C24.1, JP13.1 (A), Q21.1 (D), Q21.2 (D), Q21.5 (D), Q21.6 (D), Q21.7 (D), R18.1, R28.1, R71.1, TP10.1, U7.26 (VOUT1)
B_USB-C_BUCK_OUT_ADC: R71.2, R72.1, U12.3 (AIN4/GPIO4)
B_USB-C_CSN: L3.1, R18.2, R73.1, U7.27 (CS1)
B_USB-C_CSN_ADC: R73.2, R74.1, U12.4 (AIN5/GPIO5)
CAN_H: J9.3, JP3.2 (B), U11.7 (CANH)
CAN_L: J9.4, R59.2, U11.6 (CANL)
CAN_RX: U10.6 (GPIO12), U11.4 (RXD)
CAN_SILENT: U9.5 (P0_1), U11.8 (S)
CAN_TX: U10.7 (GPIO13), U11.1 (TXD)
CAR_12V_IN: C4.1, C9.1, Q27.5 (D), R4.1, R10.2, R52.1, U1.1 (CSP), U1.8 (BIAS)
DFP_2_N: D21.7 (CH6), J8.A7 (D-), J8.B7 (D-), U13.7 (USB2DN_DM1/PRT_DIS_M1)
DFP_2_P: D21.1 (CH1), J8.A6 (D+), J8.B6 (D+), U13.6 (USB2DN_DP1/PRT_DIS_P1)
DFP_3_RXA_N: C103.2, D22.4 (CH3), U13.12 (USB3DN_RXDM1A)
DFP_3_RXA_P: C104.1, D22.3 (CH2), U13.11 (USB3DN_RXDP1A)
DFP_3_RXB_N: C101.2, D21.4 (CH3), U13.19 (USB3DN_RXDM1B)
DFP_3_RXB_P: C102.1, D21.3 (CH2), U13.18 (USB3DN_RXDP1B)
DFP_3_TXA_N: D22.5 (CH4), J8.A3 (TX1-), U13.9 (USB3DN_TXDM1A)
DFP_3_TXA_P: D22.6 (CH5), J8.A2 (TX1+), U13.8 (USB3DN_TXDP1A)
DFP_3_TXB_N: D21.5 (CH4), J8.B3 (TX2-), U13.16 (USB3DN_TXDM1B)
DFP_3_TXB_P: D21.6 (CH5), J8.B2 (TX2+), U13.15 (USB3DN_TXDP1B)
DFP_CC1: D22.7 (CH6), J8.A5 (CC1), U16.4 (CC2)
DFP_CC2: D22.1 (CH1), J8.B5 (CC2), U16.5 (CC1)
DFP_CC_CTRL: JP15.2 (C), U16.10 (CC_CRTL1)
DFP_CC_ORIENT: U13.50 (AB1/ATTACHMUX1B/GPIO65), U16.9 (CC_ORIENT)
DFP_C_ATTACH_1: U9.9 (P0_5), U13.73 (C_ATTACH1/ATTACHMUX1A/GPIO1)
DFP_DBGACC: U9.15 (P1_2), U16.6 (DBGACC_FOUND)
DFP_PD_INT: R94.1, U16.13 (INT_N)
DFP_VBUS: J8.A4 (VBUS), J8.A9 (VBUS), J8.B4 (VBUS), J8.B9 (VBUS), Q22.1 (D), Q22.2 (D), Q22.5 (D), Q22.6 (D), Q22.7 (D), Q23.1 (D), Q23.2 (D), Q23.5 (D), Q23.6 (D), Q23.7 (D), U16.2 (VBUS)
DISP_DIG_0: U17.2 (DIG0), U18.12 (CC1)
DISP_DIG_1: U17.3 (DIG1), U18.9 (CC2)
DISP_DIG_2: U17.4 (DIG2), U18.8 (CC3)
DISP_DIG_3: U17.5 (DIG3), U18.6 (CC4)
DISP_DIG_6: D30.1 (K), D31.1 (K), D32.1 (K), D33.1 (K), D34.1 (K), U17.9 (DIG6)
DISP_DIG_7: D23.1 (K), D24.1 (K), D25.1 (K), D26.1 (K), D27.1 (K), D28.1 (K), D29.1 (K), U17.10 (DIG7)
DISP_IRQ: R99.2, U9.17 (P1_4), U17.24 (IRQ)
DISP_SEG_A: D23.2 (A), D30.2 (A), U17.15 (SEGA), U18.11 (a)
DISP_SEG_B: D24.2 (A), D31.2 (A), U17.17 (SEGB), U18.7 (b)
DISP_SEG_C: D25.2 (A), D32.2 (A), U17.20 (SEGC), U18.4 (c)
DISP_SEG_D: D26.2 (A), D33.2 (A), U17.23 (SEGD), U18.2 (d)
DISP_SEG_DP: U17.22 (SEGDP), U18.3 (DPX)
DISP_SEG_E: D27.2 (A), D34.2 (A), U17.21 (SEGE), U18.1 (e)
DISP_SEG_F: D28.2 (A), U17.16 (SEGF), U18.10 (f)
DISP_SEG_G: D29.2 (A), U17.11 (KEYA), U17.18 (SEGG), U18.5 (g)
DSUB_P_6: J9.6, JP2.2 (C)
DSUB_P_7: J9.7, JP1.2 (C)
ESP_EN: R54.2, U10.3 (EN)
ESP_IO0: C45.2, J10.5, Q17.1 (C1), R57.2, U10.18 (GPIO0)
ESP_RX: J10.6, U10.21 (GPIO3/RXD), U14.18 (TXD)
ESP_TX: J10.4, U10.22 (GPIO1/TXD), U14.17 (RXD)
F_SUB-C_BUCK_P-GOOD: R25.1, U7.7 (PG2), U8.10 (P0_6)
F_USB-C_BUCK_5V_SEL: Q12.2 (G), U8.4 (P0_0)
F_USB-C_BUCK_9V_SEL: Q13.2 (G), U8.5 (P0_1)
F_USB-C_BUCK_12V_SEL: Q14.2 (G), U8.6 (P0_2)
F_USB-C_BUCK_15V_SEL: Q15.2 (G), U8.7 (P0_3)
F_USB-C_BUCK_20V_SEL: Q16.2 (G), U8.8 (P0_4)
F_USB-C_BUCK_EN: U7.40 (EN2), U8.11 (P0_7)
F_USB-C_BUCK_FB: R39.2, R40.1, R42.1, R44.1, R46.1, R48.1, U7.3 (FB2)
F_USB-C_BUCK_OUT: C38.1, JP18.1 (A), Q25.1 (D), Q25.2 (D), Q25.5 (D), Q25.6 (D), Q25.7 (D), R26.2, R39.1, R75.1, TP11.1, U7.5 (VOUT2)
F_USB-C_BUCK_OUT_ADC: R75.2, R76.1, U12.5 (AIN6/GPIO6)
F_USB-C_CSN: L4.2, R26.1, R77.1, U7.4 (CS2)
F_USB-C_CSN_ADC: R77.2, R78.1, U12.6 (AIN7/GPIO7)
GND: C1.2, C2.2, C3.2, C4.2, C5.1, C6.2, C8.1, C9.2, C10.2, C11.2, C13.2, C14.2, C15.2, C16.2, C17.2, C19.2, C20.2, C21.2, C22.2, C23.2, C24.2, C25.1, C26.1, C27.1, C28.1, C30.1, C31.2, C32.1, C33.2, C35.1, C36.2, C37.2, C38.2, C39.2, C40.2, C41.2, C42.2, C44.1, C46.2, C47.2, C48.2, C49.2, C50.2, C51.2, C52.2, C53.2, C54.1, C55.2, C56.1, C57.1, C58.1, C59.2, C60.1, C61.2, C62.1, C63.2, C64.1, C65.1, C66.2, C67.1, C68.2, C69.1, C70.2, C71.1, C72.2, C73.1, C74.2, C75.1, C76.2, C77.1, C78.2, C79.2, C80.2, C81.2, C90.2, C95.2, C96.2, C97.2, C98.2, C99.2, C100.2, C105.2, C106.2, C107.2, C108.2, C109.2, C110.2, C111.2, C112.1, C113.2, C114.2, D2.2 (A), D8.2 (GND), D11.2 (A), D12.2 (A), D13.2 (GND), D14.2 (GND), D17.2 (A), D18.2 (A), D19.2 (GND), D20.2 (GND), D21.2 (GND), D22.2 (GND), D35.2 (GND), J3.4 (GND), J3.7 (GND_DRAIN), J4.4 (GND), J4.7 (GND_DRAIN), J5.4 (GND), J5.7 (GND_DRAIN), J6.4 (GND), J6.7 (GND_DRAIN), J7.A1 (GND), J7.A12 (GND), J7.B1 (GND), J7.B12 (GND), J8.A1 (GND), J8.A12 (GND), J8.B1 (GND), J8.B12 (GND), J9.2, J10.1, JP5.3 (B), JP6.3 (B), JP7.3 (B), JP8.3 (B), JP10.3 (B), JP15.3 (B), Q2.1 (S), Q2.2 (S), Q2.3 (S), Q4.4 (S), Q4.8 (S), Q6.4 (S), Q6.8 (S), Q7.3 (S), Q8.3 (S), Q9.3 (S), Q10.3 (S), Q11.3 (S), Q12.3 (S), Q13.3 (S), Q14.3 (S), Q15.3 (S), Q16.3 (S), Q26.2 (S), R3.2, R6.2, R7.1, R8.2, R13.2, R21.2, R24.2, R53.2, R56.2, R58.2, R64.2, R66.2, R68.2, R70.2, R72.2, R74.2, R76.2, R78.2, R80.2, R81.2, R82.1, R104.1, R106.2, SW1.2, SW2.2, SW3.2, U1.10 (PGND), U1.12 (MODE), U1.19 (AGND), U1.21 (EP), U2.2 (GND), U2.5 (EP), U3.2 (GND), U3.5 (EP), U4.9 (GND), U4.11 (EP), U5.2 (GND), U5.5 (EP), U6.2 (GND), U6.5 (EP), U7.14 (PGND2), U7.17 (PGND1), U7.34 (MODE), U7.35 (AGND), U7.41 (EP), U8.12 (VSS), U9.12 (VSS), U9.21 (ADDR), U10.15 (GND), U11.2 (VSS), U11.9 (VSS), U12.9 (GND), U12.17 (EP), U13.23 (TESTEN), U13.101 (VSS/GND), U14.3 (GND), U14.12 (GND), U14.21 (GND), U15.21 (GND), U16.14 (SLV_ADDR), U16.21 (GND), U17.6 (GND), U19.2 (GND), U19.5 (EP)
GNDS: C112.2, J3.S, J4.S, J5.S, J6.S, J7.S (SHIELD), J8.S (SHIELD), J9.S, R104.2
HUB_VBUS_DET: U9.10 (P0_6), U13.24 (VBUS_DET)
I2C_SCL: JP1.1 (A), R61.2, U8.22 (SCL), U9.22 (SCL), U10.20 (GPIO5), U12.13 (SCL), U13.75 (SMBCLK/GPIO8/SCL), U15.11 (SPI_CLK_I2C_SCL), U16.11 (SPI_CLK_I2C_SCL), U17.14 (SCL)
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

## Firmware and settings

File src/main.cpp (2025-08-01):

//{usbc car module}
//{main.cpp}
//Copyright (C) {2023}  {mickmake}
//
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
#ifndef main_cpp
#define main_cpp

#include <Arduino.h>
#include <Wire.h>
#include <ESP8266WiFi.h>
#include <ESP8266mDNS.h>
#include <WiFiClient.h>
#include <ESP8266WebServer.h>
#include <ESP8266HTTPUpdateServer.h>
#include "main_defines.h"
#include "adc.h"
#include "ui/display.h"
#include "ui/power_mon.h"
#include "pd/pd_phy.h"
#include "pd/pd_power_cont.h"
#include "pd/pd_prot.h"
#include "io.h"
#include "hub.h"
#include "i2c_scanner.h"
#include "wifi.h"
#include "debug.h"


//OTA defines
ESP8266HTTPUpdateServer httpUpdater;
ESP8266WebServer httpServer(80);

//firmware version
const char* firmware_version = "V 0.1";

//boot successful var
int boot_successful = 0;



void setup() {

  //set debug level
  debug_level_set(full);

  //begin serial
  Serial.begin(115200);
  delay(1000); // Add a delay after initializing the serial communication
  Serial.println(" ");
  Serial.println(" ");
  Serial.println("Serial started");
  Serial.print("Debug level: ");
  //Serial.println(debug_level);
  Serial.print("Firmware version: ");
  Serial.print(firmware_version);
  Serial.println(" ");

  //ask on the console 
  Serial.println("Press any key to enable Wi-Fi...");
  unsigned long wifistartTime = millis();
  while (millis() - wifistartTime < wifi_wait_time) {
    if (Serial.available()) {
      Serial.read(); // Consume the keypress
      Serial.println("Initializing Wi-Fi...");
      WiFi.begin(wifi_ssid, wifi_password);

      while (WiFi.status() != WL_CONNECTED) {
        delay(1000);
        Serial.println("Connecting to WiFi...");
      }
      Serial.println("Connected to WiFi");
      Serial.print("IP Address: ");
      Serial.println(WiFi.localIP());

      MDNS.begin("esp8266");
      httpUpdater.setup(&httpServer); // This line initializes the OTA update server
      httpServer.begin();

      MDNS.addService("http", "tcp", 80);
      Serial.printf("HTTPUpdateServer ready! Open http://%s.local/update in your browser\n", "esp8266");
      break;
    }
  }

  if (WiFi.status() != WL_CONNECTED) {
    Serial.println("Wi-Fi not enabled");
  }


  //begin i2c
  Wire.begin(sda.pin_number, scl.pin_number);
  Wire.setClock(400000);
  Serial.println("I2c started");
  debug_msg(partal_i2c, "I2c started", false, 0);

  //begin scanning i2c bus for all devices
  debug_msg(partal_i2c, "Begin i2c bus scan", false,0);
  if (bus_scan()) {
    ++boot_successful;
  }

  //begin GPIO inits for on and offboard 
  debug_msg(partal_io, "Begin GPIO init", false, 0);
  io_gpio_init();
  Serial.println("GPIO init complete");

  //begin init for ADC
  debug_msg(partal_adc, "Begin ADC init", false, 0);
  //adc_init(false);
  Serial.println("ADC init and self cal complete");

  //begin init for display
  debug_msg(partal_disp, "Begin display init", false, 0);
  disp_init();
  Serial.println("Display init complete");

  //begin USB hub chip init
  debug_msg(partal_hub, "Begin USB-hub init", false, 0);
  hub_init();
  Serial.println("USB-hub init complete");

  //begin USB-PD power supply check 
  debug_msg(partal_power_cont, "PSU self check at boot", false, 0);
  Serial.println("Begin PSU self check");
  if (pd_power_cont_self_check()) {
    Serial.println("UFP&DFP voltages within safe range");
    ++boot_successful;
  } else {
    Serial.println("PSU self check failed");
  }
  //send psu back to base state
  debug_msg(partal_power_cont, "PSU boot self check complete, returning to base state", false, 0);
  pd_power_cont_return_to_base_state(ufp);
  pd_power_cont_return_to_base_state(dfp);

  //begin init for USB-PD PHYs
  debug_msg(partal_pd_phy, "Begin USB-PD PHY UFP&DFP init", false, 0);
  pd_phy_init();
  Serial.println("USB-PD PHY UFP&DFP init complete");

  /*
    //determine if boot was successful
  if (boot_successful >= 2) {
    //do nothing
  } else {
    Serial.println("Boot failed in one or more ways !!!!!!!!!");
    while (boot_successful != 2)  {
      io_call(onboard_led, write, high);
      delay(100);
      io_call(onboard_led, write, low);
      delay(100);
    }
  }
  */
  
}



void loop() {

  //run update server
  if (WiFi.status() == WL_CONNECTED) {
    debug_msg(partal_wifi, "WiFi connected, update server called", false, 0);
    httpServer.handleClient();
    MDNS.update();
  }

  //see if interrupt was flagged and run the handler
  if (io_interrupt_flag) {
    io_intrupt_handeler();
  }

  //chck if pd prot timers are expired
  pd_prot_timer_handeler();



}


#endif // main_cpp

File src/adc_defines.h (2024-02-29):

//{usbc car module}
//{defines.cpp}
//Copyright (C) {2023}  {mickmake}
//
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
#ifndef adc_defines_h
#define adc_defines_h

#include <Arduino.h>

//adc defines
const uint8_t adc_add = 0x17;//check this 
const uint8_t adc_sys_stat = 0x00;
const uint8_t adc_gen_config = 0x01;
const uint8_t adc_data_config = 0x02;
const uint8_t adc_osr_config = 0x03;
const uint8_t adc_opmode_config = 0x04;
const uint8_t adc_pin_config = 0x05;
const uint8_t adc_gpio_config = 0x07;
const uint8_t adc_gpo_drive_config = 0x09;
const uint8_t adc_gpo_value = 0x0B;
const uint8_t adc_pgi_value = 0x0D;
const uint8_t adc_zcd_blank_config = 0x0F;
const uint8_t adc_sequence_config = 0x10;
const uint8_t adc_channel_sel = 0x11;
const uint8_t adc_auto_sequence_channel_sel = 0x12;
const uint8_t adc_alert_channel_sel = 0x14;
const uint8_t adc_alert_map = 0x16;
const uint8_t adc_alert_pin_config = 0x17;
const uint8_t adc_event_flag = 0x18;
const uint8_t adc_event_high_flag = 0x1A;
const uint8_t adc_event_low_flag = 0x1C;
const uint8_t adc_event_rgn = 0x1E;
const uint8_t adc_hysteresis_ch0 = 0x20;
const uint8_t adc_high_th_ch0 = 0x21;
const uint8_t adc_event_count_ch0 = 0x22;
const uint8_t adc_low_th_ch0 = 0x23;
const uint8_t adc_hysteresis_ch1 = 0x24;
const uint8_t adc_high_th_ch1 = 0x25;
const uint8_t adc_event_count_ch1 = 0x26;
const uint8_t adc_low_th_ch1 = 0x27;
const uint8_t adc_hysteresis_ch2 = 0x28;
const uint8_t adc_high_th_ch2 = 0x29;
const uint8_t adc_event_count_ch2 = 0x2A;
const uint8_t adc_low_th_ch2 = 0x2B;
const uint8_t adc_hysteresis_ch3 = 0x2C;
const uint8_t adc_high_th_ch3 = 0x2D;
const uint8_t adc_event_count_ch3 = 0x2E;
const uint8_t adc_low_th_ch3 = 0x2F;
const uint8_t adc_hysteresis_ch4 = 0x30;
const uint8_t adc_high_th_ch4 = 0x31;
const uint8_t adc_event_count_ch4 = 0x32;
const uint8_t adc_low_th_ch4 = 0x33;
const uint8_t adc_hysteresis_ch5 = 0x34;
const uint8_t adc_high_th_ch5 = 0x35;
const uint8_t adc_event_count_ch5 = 0x36;
const uint8_t adc_low_th_ch5 = 0x37;
const uint8_t adc_hysteresis_ch6 = 0x38;
const uint8_t adc_high_th_ch6 = 0x39;
const uint8_t adc_event_count_ch6 = 0x3A;
const uint8_t adc_low_th_ch6 = 0x3B;
const uint8_t adc_hysteresis_ch7 = 0x3C;
const uint8_t adc_high_th_ch7 = 0x3D;
const uint8_t adc_event_count_ch7 = 0x3E;
const uint8_t adc_low_th_ch7 = 0x3F;
const uint8_t adc_max_ch0_lsb = 0x60;
const uint8_t adc_max_ch0_msb = 0x61;
const uint8_t adc_max_ch1_lsb = 0x62;
const uint8_t adc_max_ch1_msb = 0x63;
const uint8_t adc_max_ch2_lsb = 0x64;
const uint8_t adc_max_ch2_msb = 0x65;
const uint8_t adc_max_ch3_lsb = 0x66;
const uint8_t adc_max_ch3_msb = 0x67;
const uint8_t adc_max_ch4_lsb = 0x68;
const uint8_t adc_max_ch4_msb = 0x69;
const uint8_t adc_max_ch5_lsb = 0x6A;
const uint8_t adc_max_ch5_msb = 0x6B;
const uint8_t adc_max_ch6_lsb = 0x6C;
const uint8_t adc_max_ch6_msb = 0x6D;
const uint8_t adc_max_ch7_lsb = 0x6E;
const uint8_t adc_max_ch7_msb = 0x6F;
const uint8_t adc_min_ch0_lsb = 0x80;
const uint8_t adc_min_ch0_msb = 0x81;
const uint8_t adc_min_ch1_lsb = 0x82;
const uint8_t adc_min_ch1_msb = 0x83;
const uint8_t adc_min_ch2_lsb = 0x84;
const uint8_t adc_min_ch2_msb = 0x85;
const uint8_t adc_min_ch3_lsb = 0x86;
const uint8_t adc_min_ch3_msb = 0x87;
const uint8_t adc_min_ch4_lsb = 0x88;
const uint8_t adc_min_ch4_msb = 0x89;
const uint8_t adc_min_ch5_lsb = 0x8A;
const uint8_t adc_min_ch5_msb = 0x8B;
const uint8_t adc_min_ch6_lsb = 0x8C;
const uint8_t adc_min_ch6_msb = 0x8D;
const uint8_t adc_min_ch7_lsb = 0x8E;
const uint8_t adc_min_ch7_msb = 0x8F;
const uint8_t adc_recent_ch0_lsb = 0xA0;
const uint8_t adc_recent_ch0_msb = 0xA1;
const uint8_t adc_recent_ch1_lsb = 0xA2;
const uint8_t adc_recent_ch1_msb = 0xA3;
const uint8_t adc_recent_ch2_lsb = 0xA4;
const uint8_t adc_recent_ch2_msb = 0xA5;
const uint8_t adc_recent_ch3_lsb = 0xA6;
const uint8_t adc_recent_ch3_msb = 0xA7;
const uint8_t adc_recent_ch4_lsb = 0xA8;
const uint8_t adc_recent_ch4_msb = 0xA9;
const uint8_t adc_recent_ch5_lsb = 0xAA;
const uint8_t adc_recent_ch5_msb = 0xAB;
const uint8_t adc_recent_ch6_lsb = 0xAC;
const uint8_t adc_recent_ch6_msb = 0xAD;
const uint8_t adc_recent_ch7_lsb = 0xAE;
const uint8_t adc_recent_ch7_msb = 0xAF;
const uint8_t adc_rms_config = 0xC0;
const uint8_t adc_rms_lsb = 0xC1;
const uint8_t adc_rms_msb = 0xC2;
const uint8_t adc_gpo0_trig_event_sel = 0xC3;
const uint8_t adc_gpo1_trig_event_sel = 0xC5;
const uint8_t adc_gpo2_trig_event_sel = 0xC7;
const uint8_t adc_gpo3_trig_event_sel = 0xC9;
const uint8_t adc_gpo4_trig_event_sel = 0xCB;
const uint8_t adc_gpo5_trig_event_sel = 0xCD;
const uint8_t adc_gpo6_trig_event_sel = 0xCF;
const uint8_t adc_gpo7_trig_event_sel = 0xD1;
const uint8_t adc_gpo_value_zcd_config_ch0_ch3 = 0xE3;
const uint8_t adc_gpo_value_zcd_config_ch4_ch7 = 0xE4;
const uint8_t adc_gpo_zcd_update_en = 0xE7;
const uint8_t adc_gpo_trigger_config = 0xE9;
const uint8_t adc_gpo_value_trig = 0xEB;
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

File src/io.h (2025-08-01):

//{usbc car module}
//{io.h}
//Copyright (C) {2023}  {mickmake}
//
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
#ifndef io_h
#define io_h

#include <Arduino.h>

//iox defines
const uint8_t iox_0_add = 0x20; //???? notshire about the addresess not shure they make sence
const uint8_t iox_1_add = 0x21;
const uint8_t iox_input_port_0 = 0x00;
const uint8_t iox_input_port_1 = 0x01;
const uint8_t iox_output_port_0 = 0x02;
const uint8_t iox_output_port_1 = 0x03;
const uint8_t iox_pol_inv_port_0 = 0x04;
const uint8_t iox_pol_inv_port_1 = 0x05;
const uint8_t iox_config_port_0 = 0x06;
const uint8_t iox_config_port_1 = 0x07;
const uint8_t iox_drive_strength_register_00 = 0x40;
const uint8_t iox_drive_strenght_register_01 = 0x41;
const uint8_t iox_drive_strenght_register_10 = 0x42;
const uint8_t iox_drive_strenght_register_11 = 0x43;
const uint8_t iox_in_latch_register_0 = 0x44;
const uint8_t iox_in_ltach_register_1 =0x45;
const uint8_t iox_pull_up_down_en_register_0 = 0x46;
const uint8_t iox_pull_up_down_en_register_1 = 0x47;
const uint8_t iox_pull_up_down_sel_register_0 = 0x48;
const uint8_t iox_pull_up_down_sel_register_1 = 0x49;
const uint8_t iox_int_mask_register_0 = 0x4a;
const uint8_t iox_int_mask_register_1 = 0x4b;
const uint8_t iox_int_stat_register_0 = 0x4c;
const uint8_t iox_int_stat_register_1 = 0x4d;
const uint8_t iox_out_port_config_register = 0x4f;

//io_call struct setup
enum in_out {
  in,       //input
  out,      //output
  bi_dir,   //bi-directional pin only used for i2c and spi comms
  intr,     //used for software interupts only works with onboard pins
  empty_pin //empty for empty pin object
};

struct pin {
  char pin_ident;        //name of pin uneque identifyer for eatch pin only used in itrupt handeler
  uint8_t mask;          //mask for iox
  int port;              //port on iox (can be 0 or 1 only)
  int iox_number;        //iox number
  int pin_number;        //pin number, for ESP-12F: GPIO#, for iox: phisical pin#
  in_out pin_mode;       //defines pinmode see enum above for deatails
  bool onboard;          //If true, IO is on ESP8266; if false, IO is on IO expander

};
//BE SURE TO ADD PINS TO BOTH THE "pin" STRUCT AND THE "pin_names" ARRAY THEY MUST MATCH
//io_call struct defines  {pin_ident, mask, port, iox#, pin, pin_mode, onboard}
static struct pin sda {'a', 0x00, 0, 0, 4, bi_dir, true};
static struct pin scl {'b', 0x00, 0, 0, 5, bi_dir, true};
static struct pin iox_0_int {'g', 0x00, 0, 1, 2, intr, true};
static struct pin iox_1_int {'h', 0x01, 0, 1, 4, intr, false};
static struct pin can_int {'c', 0x02, 0, 0, 5, intr, true};
static struct pin dfp_cc_orient {'i', 0x80, 0, 0, 8, out, false};
static struct pin b_usbc_pgood {'j', 0x20, 1, 1, 9, in, false};
static struct pin b_usbc_buck_en {'k', 0x01, 1, 1, 13, out, false};
static struct pin b_usbc_5V_sel {'l', 0x02, 1, 1, 14, out, false};
static struct pin b_usbc_9V_sel {'m', 0x04, 1, 1, 15, out, false};
static struct pin b_usbc_12V_sel {'n', 0x08, 1, 1, 16, out, false};
static struct pin b_usbc_15V_sel {'o', 0x10, 1, 1, 17, out, false};
static struct pin b_usbc_20V_sel {'p', 0x20, 1, 1, 18, out, false};
static struct pin f_usbc_pgood {'q', 0x40, 1, 1, 10, in, false};
static struct pin f_usbc_buck_en {'r', 0x80, 1, 1, 11, out, false};
static struct pin f_usbc_5V_sel {'s', 0x01, 1, 1, 4, out, false};
static struct pin f_usbc_9V_sel {'t', 0x02, 1, 1, 5, out, false};
static struct pin f_usbc_12V_sel {'u', 0x04, 1, 1, 6, out, false};
static struct pin f_usbc_15V_sel {'v', 0x08, 1, 1, 7, out, false};
static struct pin f_usbc_20V_sel {'w', 0x10, 1, 1, 8, out, false};
static struct pin adc_alert {'x', 0x80, 1, 1, 20, intr, false};
static struct pin ufp_c_attach_0 {'y', 0x80, 0, 0, 11, out, false};
static struct pin hub_vbus_det {'z', 0x40, 0, 0, 10, out, false};
static struct pin dfp_c_attach_1 {'1', 0x20, 0, 0, 9, out, false};
static struct pin disp_irq {'2', 0x10, 0, 0, 17, intr, false};
static struct pin unit_btn {'3', 0x40, 0, 0, 19, intr, false};
static struct pin src_btn {'4', 0x80, 0, 0, 20, intr, false};
static struct pin mode_btn {'5', 0x20, 0, 0, 18, intr, false};
static struct pin iox_0_p_0_0 {'6', 0x08, 0, 0, 7, in, false};
static struct pin iox_0_p_0_1 {'7', 0x04, 0, 0, 6, in, false};
static struct pin ufp_dbgacc {'8', 0x04, 1, 0, 15, in, false};
static struct pin dfp_dbgacc {'9', 0x80, 1, 1, 19, in, false};
static struct pin ufp_alert_n {'0', 0x02, 1, 0, 14, intr, false};
static struct pin dfp_alert_n {'?', 0x01, 1, 0, 13, intr, false};
static struct pin ufp_cc_orient {'~', 0x10, 0, 0, 8, out, false};
static struct pin empty_struct_pin {'!', 0x0, 0, 0, 0, empty_pin, false};
static struct pin can_si {'@', 0x00, 0, 0, 12, bi_dir, true};
static struct pin can_so {'#', 0x00, 0, 0, 13, bi_dir, true};
static struct pin can_sck {'$', 0x00, 0, 0, 14, bi_dir, true};
static struct pin can_cs {'%', 0x00, 0, 0, 15, bi_dir, true};

//Array of pin structs for automatic pin initialization
static struct pin* pin_names[] = {
  &sda,
  &scl,
  &iox_0_int,
  &iox_1_int,
  &can_int,
  &dfp_cc_orient,
  &b_usbc_pgood,
  &b_usbc_buck_en,
  &b_usbc_5V_sel,
  &b_usbc_9V_sel,
  &b_usbc_12V_sel,
  &b_usbc_15V_sel,
  &b_usbc_20V_sel,
  &f_usbc_pgood,
  &f_usbc_buck_en,
  &f_usbc_5V_sel,
  &f_usbc_9V_sel,
  &f_usbc_12V_sel,
  &f_usbc_15V_sel,
  &f_usbc_20V_sel,
  &adc_alert,
  &ufp_c_attach_0,
  &hub_vbus_det,
  &dfp_c_attach_1,
  &disp_irq,
  &unit_btn,
  &src_btn,
  &mode_btn,
  &iox_0_p_0_0,
  &iox_0_p_0_1,
  &ufp_dbgacc,
  &dfp_dbgacc,
  &ufp_alert_n,
  &dfp_alert_n,
  &ufp_cc_orient,
  &empty_struct_pin,
  &can_si,
  &can_so,
  &can_sck,
  &can_cs
};


//read write enum define for io_call function
enum read_write {
  read,
  write
};

//io_call high low input enum
enum high_low {
  high,
  low,
  read_mode
};

//iox interrupt register values
extern uint8_t iox_0_port_0_interrupt;
extern uint8_t iox_0_port_1_interrupt;
extern uint8_t iox_1_port_0_interrupt;
extern uint8_t iox_1_port_1_interrupt;
extern bool io_interrupt_flag;

//button info defines
extern bool io_unit_btn_pressed;
extern unsigned long io_unit_btn_pressed_time;
extern bool io_mode_btn_pressed;
extern unsigned long io_mode_btn_pressed_time;
extern bool io_src_btn_pressed;
extern unsigned long io_src_btn_pressed_time;

//message received interrupt flags
extern bool io_interrupt_ufp_msg_received;
extern bool io_interrupt_dfp_msg_received;
 
//function defines
uint8_t io_read_current_io_state(u_int8_t port, u_int8_t iox_num);
int io_call(struct pin pin_needed, enum read_write read_write, enum high_low high_low);
void io_gpio_init();
struct pin io_determine_interrupt_source();
void io_pin_interrupt_flagger();
void io_intrupt_handeler();



#endif // io_h

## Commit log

2023-09-09 inital commit
    [5V USB-A AND MCU POWER.kicad_sch, FRONT USB-C POWER.kicad_sch, LM(2)5143-Q1 quickstart design tool - revB2.xlsm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]
2023-09-09 working on adujustabel otpur for usbpd
    [FRONT USB-C POWER.kicad_sch, F_AND_B_VOUT_FEEDBACK_NETWORKS.kicad_sch]
2023-09-09 making hardware progress
    [5V USB-A AND MCU POWER.kicad_sch, ADC.kicad_sch, ESP-12F.kicad_sch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]
2023-09-10 working on usb side implimentaion
    [5V USB-A AND MCU POWER.kicad_sch, ADC.kicad_sch, ESP-12F.kicad_sch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]
2023-09-10 fixed desync
    [ADC.kicad_sch, ESP-12F.kicad_sch, F_AND_B_VOUT_FEEDBACK_NETWORKS.kicad_sch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]
2023-09-15 working on io fugtions
    [HUBCHIP.kicad_sch, USB_UART.kicad_sch]
2023-09-15 working on io_call and auto init for pins
    [ESP-12F.kicad_sch, HUBCHIP.kicad_sch, USB_UART.kicad_sch]
2023-09-22 gave up on ebedding date and time in the firmware workingon adding the adc
2023-09-22 still working on adc
2023-09-23 working on hardware agin as well as implimentded auto adc init and read
    [ADC.kicad_sch, BACK_UFP_USB_C_PORT.kicad_sch, ESP-12F.kicad_sch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]
2023-09-26 finnished rudimentry schimatics still needs alot of work
    [5V USB-A AND MCU POWER.kicad_sch, CAR_12V_IN.kicad_sch, ESP-12F.kicad_sch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]
2023-09-27 working on hardware
    [5V USB-A AND MCU POWER.kicad_sch, ADC.kicad_sch, BACK_UFP_USB_C_PORT.kicad_sch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]
2023-09-28 working assighning footprints still
    [5V USB-A AND MCU POWER.kicad_sch, ADC.kicad_sch, BACK_UFP_USB_C_PORT.kicad_sch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]
2023-09-29 FINALY starting the pcb
    [5V USB-A AND MCU POWER.kicad_sch, BACK_UFP_USB_C_PORT.kicad_sch, CAR_12V_IN.kicad_sch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]
2023-09-29 coldent sleep so came back and did somre routing
    [5V USB-A AND MCU POWER.kicad_sch, ADC.kicad_sch, BACK_UFP_USB_C_PORT.kicad_sch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]
2023-09-30 working on routing still finnished psu section
    [ADC.kicad_sch, BACK_UFP_USB_C_PORT.kicad_sch, ESP-12F.kicad_sch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]
2023-10-01 worked on usb port and display routing
    [BACK_UFP_USB_C_PORT.kicad_sch, ESP-12F.kicad_sch, FRONT_DFP_USB_C_PORT.kicad_sch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]
2023-10-02 working in final routing
    [BACK_UFP_USB_C_PORT.kicad_sch, FRONT_DFP_USB_C_PORT.kicad_sch, HUBCHIP.kicad_sch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]
2023-10-09 finaliseing pcb layout will come back later for a fresh look
    [5V USB-A AND MCU POWER.kicad_sch, ADC.kicad_sch, BACK_UFP_USB_C_PORT.kicad_sch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]
2023-10-18 messing arround with pcb to finalise
    [5V USB-A AND MCU POWER.kicad_sch, BACK_UFP_USB_C_PORT.kicad_sch, FRONT USB-C POWER.kicad_sch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]
2023-10-20 fialiseing pcb for production
    [BACK_UFP_USB_C_PORT.kicad_sch, CAR_12V_IN.kicad_sch, FRONT_DFP_USB_C_PORT.kicad_sch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]
2023-11-20 ned to fix port swap before prod
    [BACK_UFP_USB_C_PORT.kicad_sch, FRONT_DFP_USB_C_PORT.kicad_sch, HUBCHIP.kicad_sch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]
2023-11-24 working on fixing pcb impeedance
    [BACK_UFP_USB_C_PORT.kicad_sch, ESP-12F.kicad_sch, FRONT_DFP_USB_C_PORT.kicad_sch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]
2024-02-18 fixed DP issues and finneshed overall routeing
    [5V USB-A AND MCU POWER.kicad_sch, BACK_UFP_USB_C_PORT.kicad_sch, ESP-12F.kicad_sch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]
2024-02-19 minor revisions
    [5V USB-A AND MCU POWER.kicad_sch, ADC.kicad_sch, BACK_UFP_USB_C_PORT.kicad_sch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]
2024-02-26 minor pre prod chnages
    [usbc-car-module-B_Cu.gbr, usbc-car-module-B_Mask.gbr, usbc-car-module-B_Paste.gbr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]
2024-02-29 working on complie issues
    [BACK_UFP_USB_C_PORT.kicad_sch, FRONT_DFP_USB_C_PORT.kicad_sch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]
2024-03-01 switched pd phy as old one needed an NDA
    [BACK_UFP_USB_C_PORT.kicad_sch, ESP-12F.kicad_sch, FRONT_DFP_USB_C_PORT.kicad_sch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]
2024-03-04 working on usb pd protocol implimentation
    [USB_UART.kicad_sch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]
2024-03-05 fixingt things
    [current stock.xlsx]
2024-03-06 working on things
    [HUBCHIP.kicad_sch]
2024-03-06 minor pcb change
    [usbc-car-module-B_Cu.gbr, usbc-car-module-B_Mask.gbr, usbc-car-module-B_Paste.gbr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]
2024-03-06 fixed_watchdog hang from pd_phy_init
    [main.cpp, pd_phy.cpp]
2024-04-29 migrated to kicad 8
2024-04-30 updated block digram minor pcb changes
    [5V USB-A AND MCU POWER.kicad_sch, ADC.kicad_sch, BACK_UFP_USB_C_PORT.kicad_sch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]
2024-05-22 improved documentation fixed timer controler and fixed wifi
    [adc.cpp, display.cpp, hub.cpp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]
2024-05-22 added eeprom for nonvol memory
    [5V USB-A AND MCU POWER.kicad_sch, ADC.kicad_sch, BACK_UFP_USB_C_PORT.kicad_sch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]
2024-05-26 fixed a shiton of spelling mistakes and some minor refactoring
    [ESP-12F.kicad_sch]
2024-05-26 fixed some copilot fuckups
    [adc.cpp, hub.cpp, main.cpp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]
2024-07-31 switched can tranceiver to combo controler and tranceiver
    [5V USB-A AND MCU POWER.kicad_sch, BACK_UFP_USB_C_PORT.kicad_sch, CAR_12V_IN.kicad_sch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]
2024-11-14 workiing on some inturpt otimiseation and pin init issues
    [io.cpp, io.h, main.cpp]
2024-11-16 kicad version upgrade and minor pcb changes
    [ESP-12F.kicad_sch, HUBCHIP.kicad_sch, USB_UART.kicad_sch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]
2025-08-01 migrated to the esp32-s2 and starting new board revison
    [5V USB-A AND MCU POWER.kicad_sch, ADC.kicad_sch, BACK_UFP_USB_C_PORT.kicad_sch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]

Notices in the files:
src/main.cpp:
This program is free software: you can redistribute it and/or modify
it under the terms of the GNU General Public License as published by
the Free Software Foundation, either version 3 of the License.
